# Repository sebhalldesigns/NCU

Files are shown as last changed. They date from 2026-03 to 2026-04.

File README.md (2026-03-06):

# NCU
NCU (Network Control Unit)

## Main Connector Pinout

GND
12V

CAN0_L
CAN0_H
CAN1_L
CAN1_H

ETH_TXP
ETH_TXM
ETH_RXP
ETH_RXM

USB_VBUS
USB_DP
USB_DM
GND

AN_5V
AN_GND
AIN_0
AIN_1
AIN_2
AIN_3
AIN_4
AIN_5
AIN_6
AIN_7

HSD_0
HSD_1
HSD_2
HSD_3

LSD_0
LSD_1
LSD_2
LSD_3

TOTAL:
30

## Sheets

Root/
    CONN_A - OK
    CONN_B - OK
    PWR/ - OK
        PWR_LV_5V - OK
        PWR_3V3 - OK
        PWR_A5V - OK
        PWR_MUX - OK
    PHY_CAN/ - OK
        CAN_BUS (x2) - OK
    PHY_ETH - OK
    DRIVES/ - OK
        LSD (x2) - OK
        HSD (x2) - OK
    INPUTS/ - OK
        INPUT_5V (x4) - OK
        INPUT_20V (x5) - OK
    GPIO/ - OK
        INPUT_3V3 (x4) - OK
    CARD_SD - OK
    CARD_SIM - OK
    MOD_WLAN - BAD
    MOD_PCIE - BAD
    MCU - BAD

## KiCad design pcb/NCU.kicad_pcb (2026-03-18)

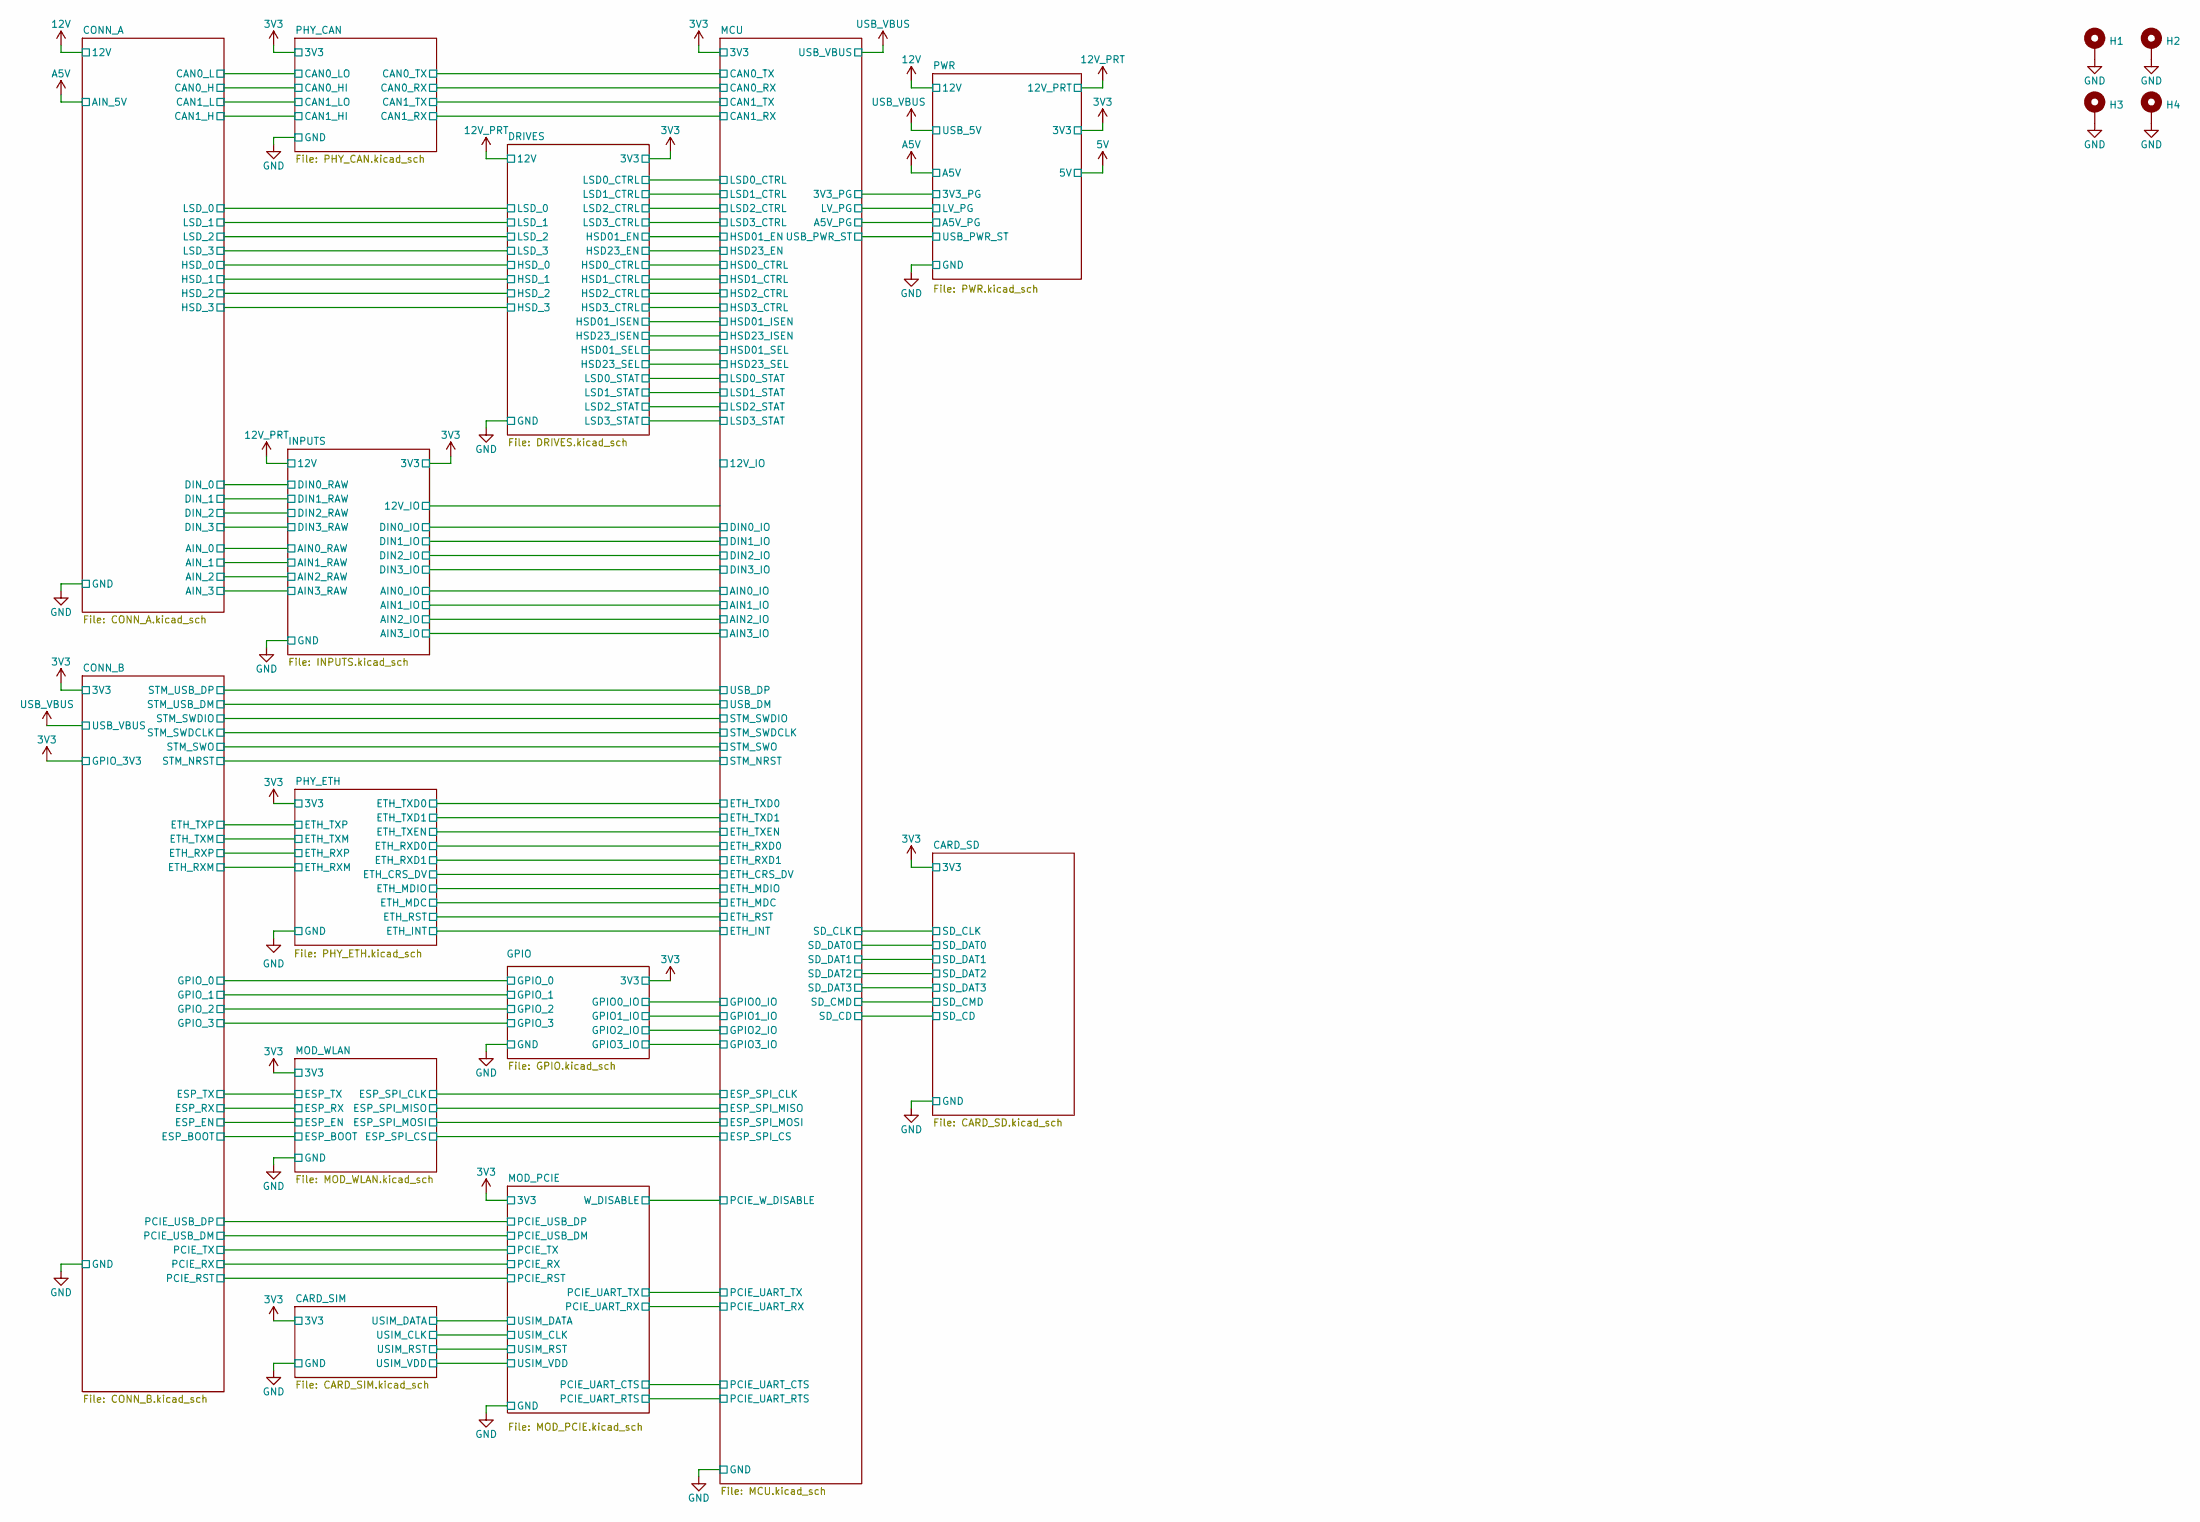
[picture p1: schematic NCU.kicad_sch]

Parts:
H1, H2, H3, H4: MountingHole; MountingHole_3.2mm_M3_Pad

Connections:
GND: H1.1, H2.1, H3.1, H4.1; also elsewhere on the board

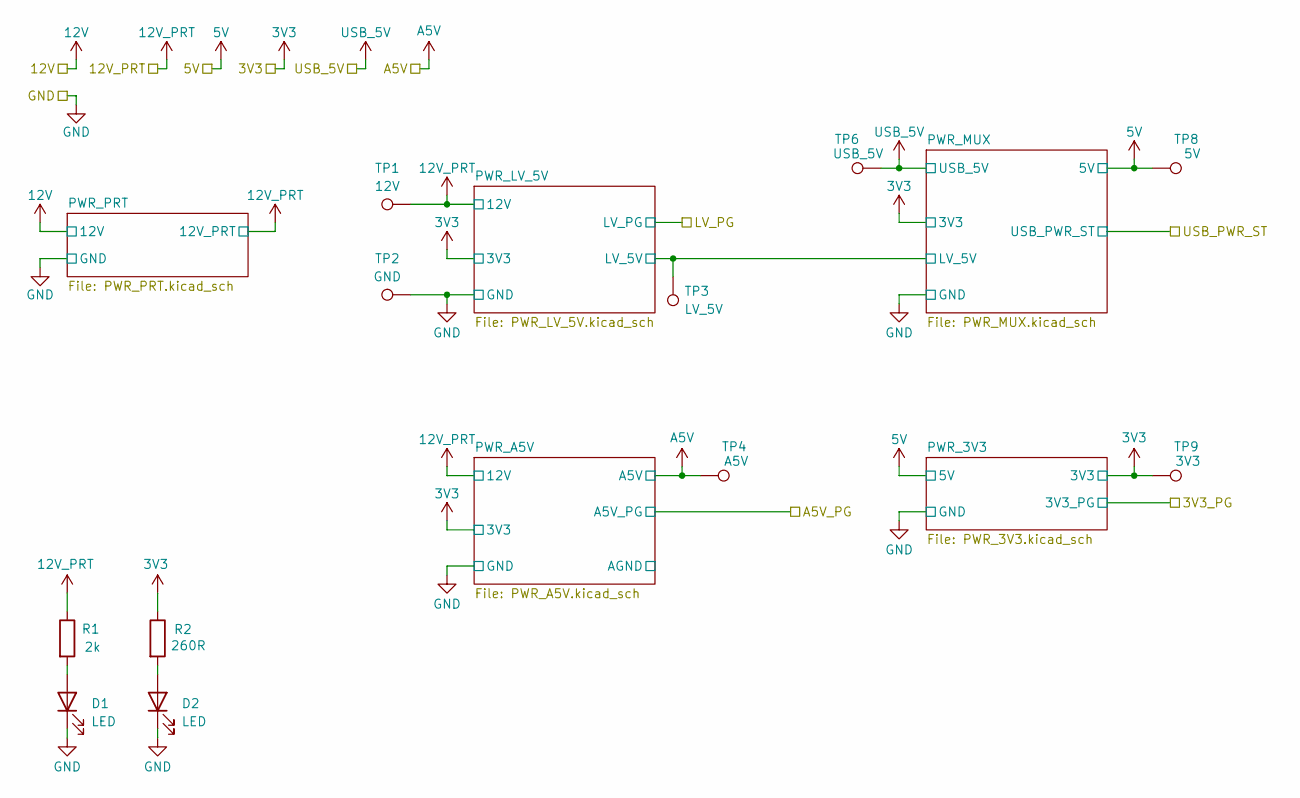
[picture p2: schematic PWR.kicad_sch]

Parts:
D1, D2: LED; LED_0603_1608Metric_Pad1.05x0.95mm_HandSolder
R1: 2k; R_0603_1608Metric_Pad0.98x0.95mm_HandSolder
R2: 260R; R_0603_1608Metric_Pad0.98x0.95mm_HandSolder
TP1: 12V; TestPoint_THTPad_D2.0mm_Drill1.0mm
TP2: GND; TestPoint_THTPad_D2.0mm_Drill1.0mm
TP3: LV_5V; TestPoint_THTPad_D2.0mm_Drill1.0mm
TP4: A5V; TestPoint_THTPad_D2.0mm_Drill1.0mm
TP6: USB_5V; TestPoint_THTPad_D2.0mm_Drill1.0mm
TP8: 5V; TestPoint_THTPad_D2.0mm_Drill1.0mm
TP9: 3V3; TestPoint_THTPad_D2.0mm_Drill1.0mm

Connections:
3V3: R2.1, TP9.1; also elsewhere on the board
5V: TP8.1; also elsewhere on the board
12V_PRT: R1.1, TP1.1; also elsewhere on the board
A5V: TP4.1; also elsewhere on the board
GND: D1.1 (K), D2.1 (K), TP2.1; also elsewhere on the board
LV_5V: TP3.1; also elsewhere on the board
unnamed: D1.2 (A), R1.2
unnamed: D2.2 (A), R2.2
USB_VBUS: TP6.1; also elsewhere on the board

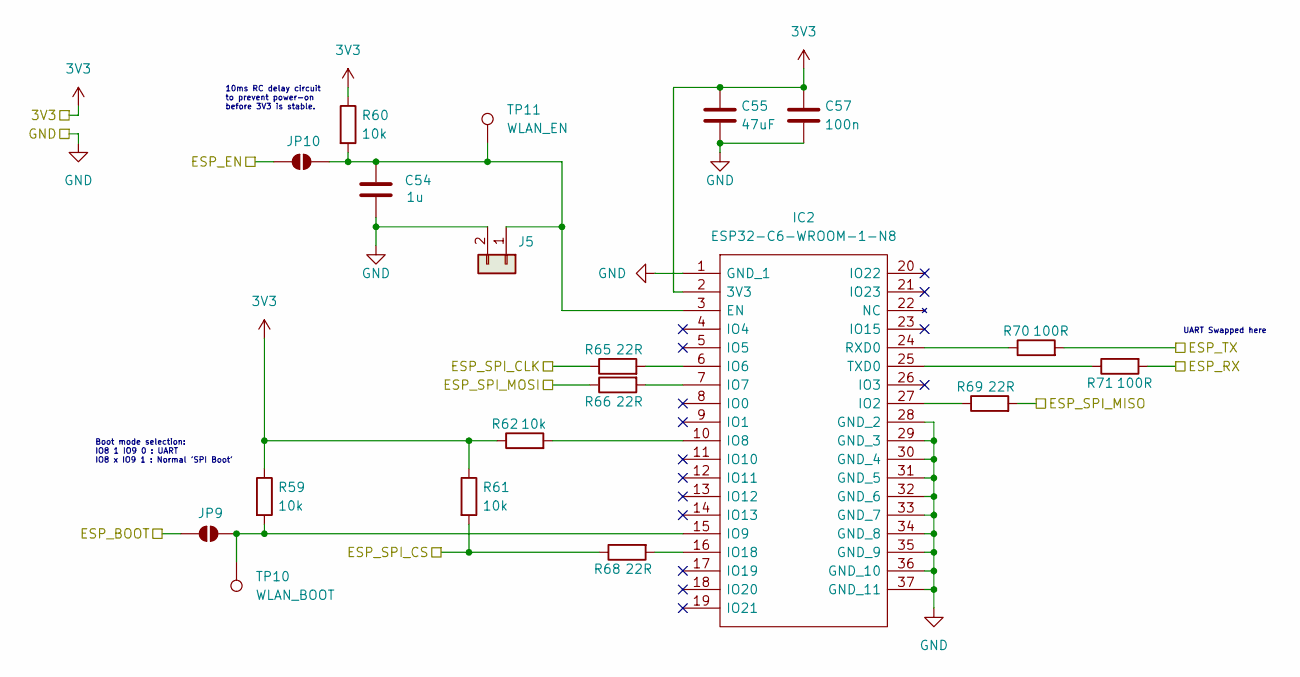
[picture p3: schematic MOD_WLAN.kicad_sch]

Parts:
C54: 1u; C_0603_1608Metric_Pad1.08x0.95mm_HandSolder
C55: 47uF; C_0603_1608Metric_Pad1.08x0.95mm_HandSolder
C57: 100n; C_0603_1608Metric_Pad1.08x0.95mm_HandSolder
IC2: ESP32-C6-WROOM-1-N8; ESP32C6WROOM1N8; Mouser Part Number 356-ESP32C6WROOM1N8
J5: Conn_01x02; PinHeader_1x02_P2.54mm_Vertical
JP9, JP10: SolderJumper_2_Open; SolderJumper-2_P1.3mm_Open_RoundedPad1.0x1.5mm
R59, R60, R61, R62: 10k; R_0603_1608Metric_Pad0.98x0.95mm_HandSolder
R65, R66, R68, R69: 22R; R_0603_1608Metric_Pad0.98x0.95mm_HandSolder
R70, R71: 100R; R_0603_1608Metric_Pad0.98x0.95mm_HandSolder
TP10: WLAN_BOOT; TestPoint_THTPad_D2.0mm_Drill1.0mm
TP11: WLAN_EN; TestPoint_THTPad_D2.0mm_Drill1.0mm

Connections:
3V3: C55.1, C57.1, IC2.2 (3V3), R59.1, R60.1, R61.1, R62.1; also elsewhere on the board
/CONN_B/ESP_BOOT: JP9.1 (A); also elsewhere on the board
/CONN_B/ESP_EN: JP10.1 (A); also elsewhere on the board
/CONN_B/ESP_RX: R71.2; also elsewhere on the board
/CONN_B/ESP_TX: R70.2; also elsewhere on the board
/MCU/ESP_SPI_CLK: R65.1; also elsewhere on the board
/MCU/ESP_SPI_CS: R61.2, R68.1; also elsewhere on the board
/MCU/ESP_SPI_MISO: R69.2; also elsewhere on the board
/MCU/ESP_SPI_MOSI: R66.1; also elsewhere on the board
GND: C54.2, C55.2, C57.2, IC2.1 (GND_1), IC2.28 (GND_2), IC2.29 (GND_3), IC2.30 (GND_4), IC2.31 (GND_5), IC2.32 (GND_6), IC2.33 (GND_7), IC2.34 (GND_8), IC2.35 (GND_9), IC2.36 (GND_10), IC2.37 (GND_11), J5.2; also elsewhere on the board
unnamed: C54.1, IC2.3 (EN), J5.1, JP10.2 (B), R60.2, TP11.1
unnamed: IC2.27 (IO2), R69.1
unnamed: IC2.6 (IO6), R65.2
unnamed: IC2.7 (IO7), R66.2
unnamed: IC2.10 (IO8), R62.2
unnamed: IC2.15 (IO9), JP9.2 (B), R59.2, TP10.1
unnamed: IC2.16 (IO18), R68.2
unnamed: IC2.24 (RXD0), R70.1
unnamed: IC2.25 (TXD0), R71.1

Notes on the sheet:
Boot mode selection: IO8 1 IO9 0 : UART IO8 x IO9 1 : Normal 'SPI Boot'
10ms RC delay circuit to prevent power-on before 3V3 is stable.
UART Swapped here

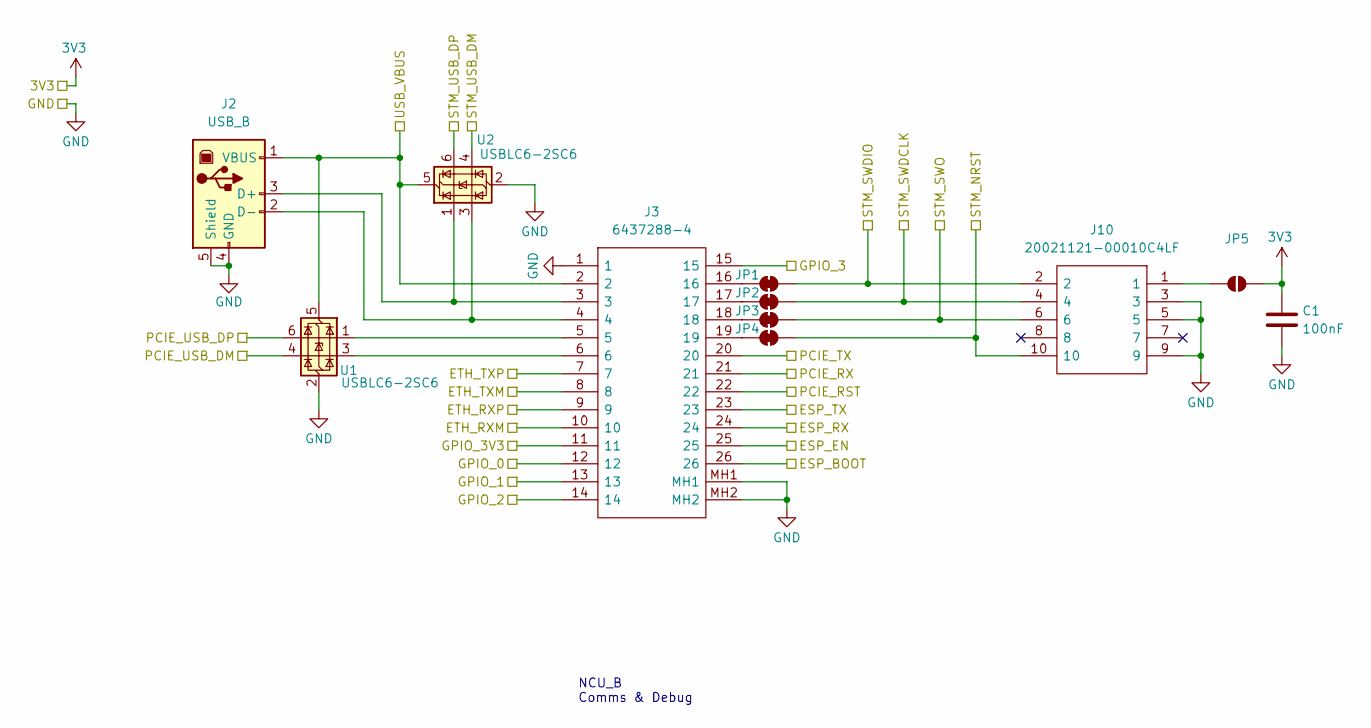
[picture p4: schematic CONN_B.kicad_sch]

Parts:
C1: 100nF; C_0603_1608Metric_Pad1.08x0.95mm_HandSolder
J2: USB_B; USB_B_OST_USB-B1HSxx_Horizontal
J3: 6437288-4; 64372884; Mouser Part Number 571-6437288-4
J10: 20021121-00010C4LF; 2002112100010C4LF; Mouser Part Number 649-202112100010C4LF
JP1, JP2, JP3, JP4: SolderJumper_2_Bridged; SolderJumper-2_P1.3mm_Bridged_RoundedPad1.0x1.5mm
JP5: SolderJumper_2_Open; SolderJumper-2_P1.3mm_Open_RoundedPad1.0x1.5mm
U1, U2: USBLC6-2SC6; SOT-23-6

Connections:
3V3: C1.1, J3.11, JP5.2 (B); also elsewhere on the board
/CONN_B/ESP_BOOT: J3.26; also elsewhere on the board
/CONN_B/ESP_EN: J3.25; also elsewhere on the board
/CONN_B/ESP_RX: J3.24; also elsewhere on the board
/CONN_B/ESP_TX: J3.23; also elsewhere on the board
/CONN_B/ETH_RXM: J3.10; also elsewhere on the board
/CONN_B/ETH_RXP: J3.9; also elsewhere on the board
/CONN_B/ETH_TXM: J3.8; also elsewhere on the board
/CONN_B/ETH_TXP: J3.7; also elsewhere on the board
/CONN_B/GPIO_0: J3.12; also elsewhere on the board
/CONN_B/GPIO_1: J3.13; also elsewhere on the board
/CONN_B/GPIO_2: J3.14; also elsewhere on the board
/CONN_B/GPIO_3: J3.15; also elsewhere on the board
/CONN_B/PCIE_RST: J3.22; also elsewhere on the board
/CONN_B/PCIE_RX: J3.21; also elsewhere on the board
/CONN_B/PCIE_TX: J3.20; also elsewhere on the board
/CONN_B/PCIE_USB_DM: U1.4 (I/O2); also elsewhere on the board
/CONN_B/PCIE_USB_DP: U1.6 (I/O1); also elsewhere on the board
/CONN_B/STM_SWDCLK: J10.4, JP2.2 (B); also elsewhere on the board
/CONN_B/STM_SWDIO: J10.2, JP1.2 (B); also elsewhere on the board
/CONN_B/STM_SWO: J10.6, JP3.2 (B); also elsewhere on the board
/CONN_B/STM_USB_DM: U2.4 (I/O2); also elsewhere on the board
/CONN_B/STM_USB_DP: U2.6 (I/O1); also elsewhere on the board
/MCU/STM_NRST: J10.10, JP4.2 (B); also elsewhere on the board
GND: C1.2, J2.4 (GND), J2.5 (Shield), J3.1, J3.MH1, J3.MH2, J10.3, J10.5, J10.9, U1.2 (GND), U2.2 (GND); also elsewhere on the board
unnamed: J2.3 (D+), J3.3, U2.1 (I/O1)
unnamed: J2.2 (D-), J3.4, U2.3 (I/O2)
unnamed: J3.5, U1.1 (I/O1)
unnamed: J3.6, U1.3 (I/O2)
unnamed: J3.16, JP1.1 (A)
unnamed: J3.17, JP2.1 (A)
unnamed: J3.18, JP3.1 (A)
unnamed: J3.19, JP4.1 (A)
unnamed: J10.1, JP5.1 (A)
USB_VBUS: J2.1 (VBUS), J3.2, U1.5 (VBUS), U2.5 (VBUS); also elsewhere on the board

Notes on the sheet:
NCU_B Comms & Debug

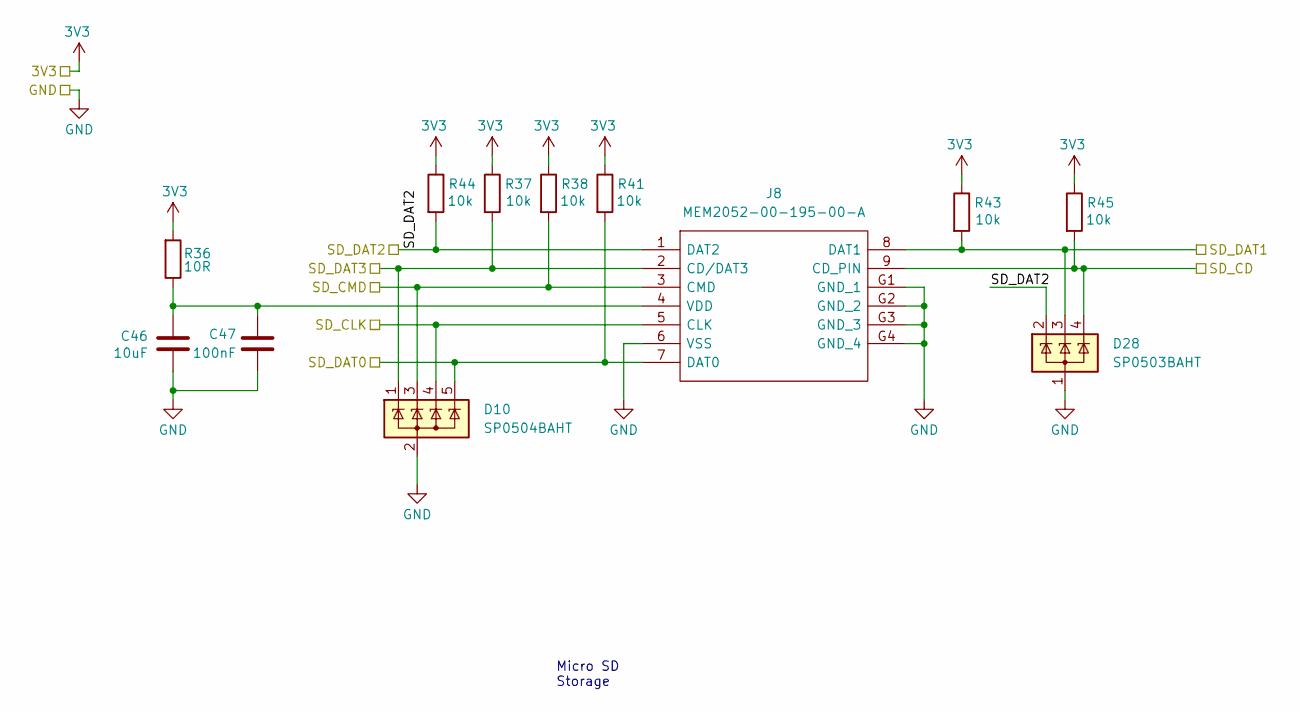
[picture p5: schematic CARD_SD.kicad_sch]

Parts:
C46: 10uF; C_0603_1608Metric_Pad1.08x0.95mm_HandSolder
C47: 100nF; C_0603_1608Metric_Pad1.08x0.95mm_HandSolder
D10: SP0504BAHT; SOT-23-5
D28: SP0503BAHT; SOT-143
J8: MEM2052-00-195-00-A; MEM20520019500A; Mouser Part Number 640-MEM20520019500A
R36: 10R; R_0603_1608Metric_Pad0.98x0.95mm_HandSolder
R37, R38, R41, R43, R44, R45: 10k; R_0603_1608Metric_Pad0.98x0.95mm_HandSolder

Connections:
3V3: R36.2, R37.1, R38.1, R41.1, R43.1, R44.1, R45.1; also elsewhere on the board
/CARD_SD/SD_CD: D28.4 (K), J8.9 (CD_PIN), R45.2; also elsewhere on the board
/CARD_SD/SD_CLK: D10.4 (K), J8.5 (CLK); also elsewhere on the board
/CARD_SD/SD_CMD: D10.3 (K), J8.3 (CMD), R38.2; also elsewhere on the board
/CARD_SD/SD_DAT0: D10.5 (K), J8.7 (DAT0), R41.2; also elsewhere on the board
/CARD_SD/SD_DAT1: D28.3 (K), J8.8 (DAT1), R43.2; also elsewhere on the board
/CARD_SD/SD_DAT2: D28.2 (K), J8.1 (DAT2), R44.2; also elsewhere on the board
/CARD_SD/SD_DAT3: D10.1 (K), J8.2 (CD/DAT3), R37.2; also elsewhere on the board
GND: C46.2, C47.2, D10.2 (A), D28.1 (A), J8.6 (VSS), J8.G1 (GND_1), J8.G2 (GND_2), J8.G3 (GND_3), J8.G4 (GND_4); also elsewhere on the board
unnamed: C46.1, C47.1, J8.4 (VDD), R36.1

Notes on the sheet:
Micro SD Storage

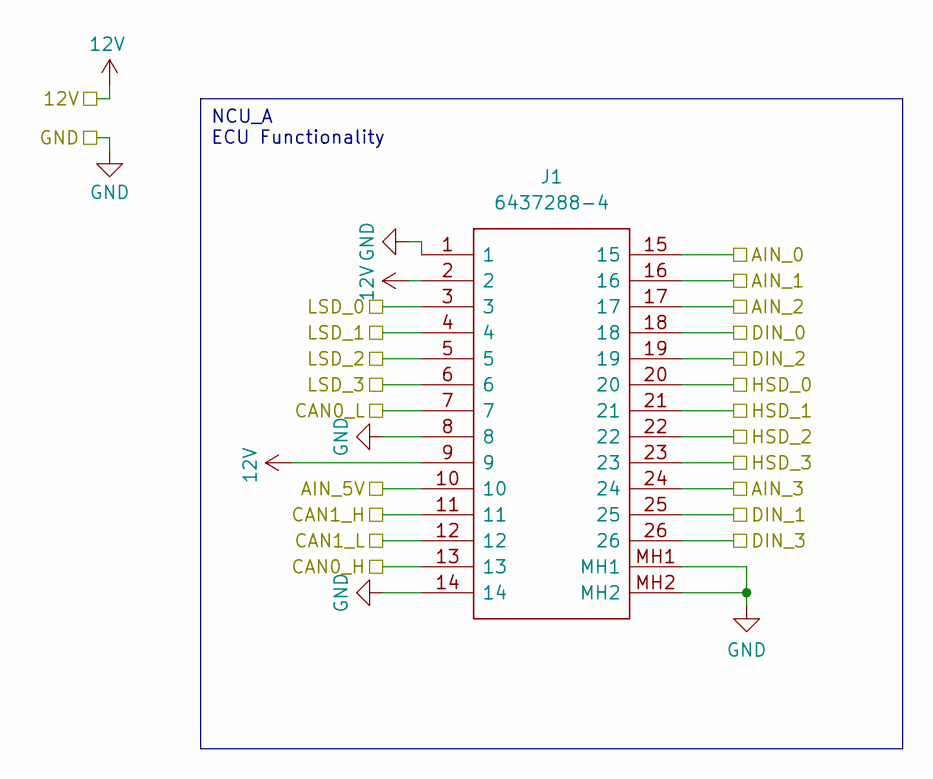
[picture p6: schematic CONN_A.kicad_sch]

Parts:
J1: 6437288-4; 64372884; Mouser Part Number 571-6437288-4

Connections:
12V: J1.2, J1.9; also elsewhere on the board
/CONN_A/AIN_0: J1.15; also elsewhere on the board
/CONN_A/AIN_1: J1.16; also elsewhere on the board
/CONN_A/AIN_2: J1.17; also elsewhere on the board
/CONN_A/AIN_3: J1.24; also elsewhere on the board
/CONN_A/CAN0_H: J1.13; also elsewhere on the board
/CONN_A/CAN0_L: J1.7; also elsewhere on the board
/CONN_A/CAN1_H: J1.11; also elsewhere on the board
/CONN_A/CAN1_L: J1.12; also elsewhere on the board
/CONN_A/DIN_0: J1.18; also elsewhere on the board
/CONN_A/DIN_1: J1.25; also elsewhere on the board
/CONN_A/DIN_2: J1.19; also elsewhere on the board
/CONN_A/DIN_3: J1.26; also elsewhere on the board
/CONN_A/HSD_0: J1.20; also elsewhere on the board
/CONN_A/HSD_1: J1.21; also elsewhere on the board
/CONN_A/HSD_2: J1.22; also elsewhere on the board
/CONN_A/HSD_3: J1.23; also elsewhere on the board
/CONN_A/LSD_0: J1.3; also elsewhere on the board
/CONN_A/LSD_1: J1.4; also elsewhere on the board
/CONN_A/LSD_2: J1.5; also elsewhere on the board
/CONN_A/LSD_3: J1.6; also elsewhere on the board
A5V: J1.10; also elsewhere on the board
GND: J1.1, J1.8, J1.14, J1.MH1, J1.MH2; also elsewhere on the board

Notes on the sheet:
NCU_A ECU Functionality

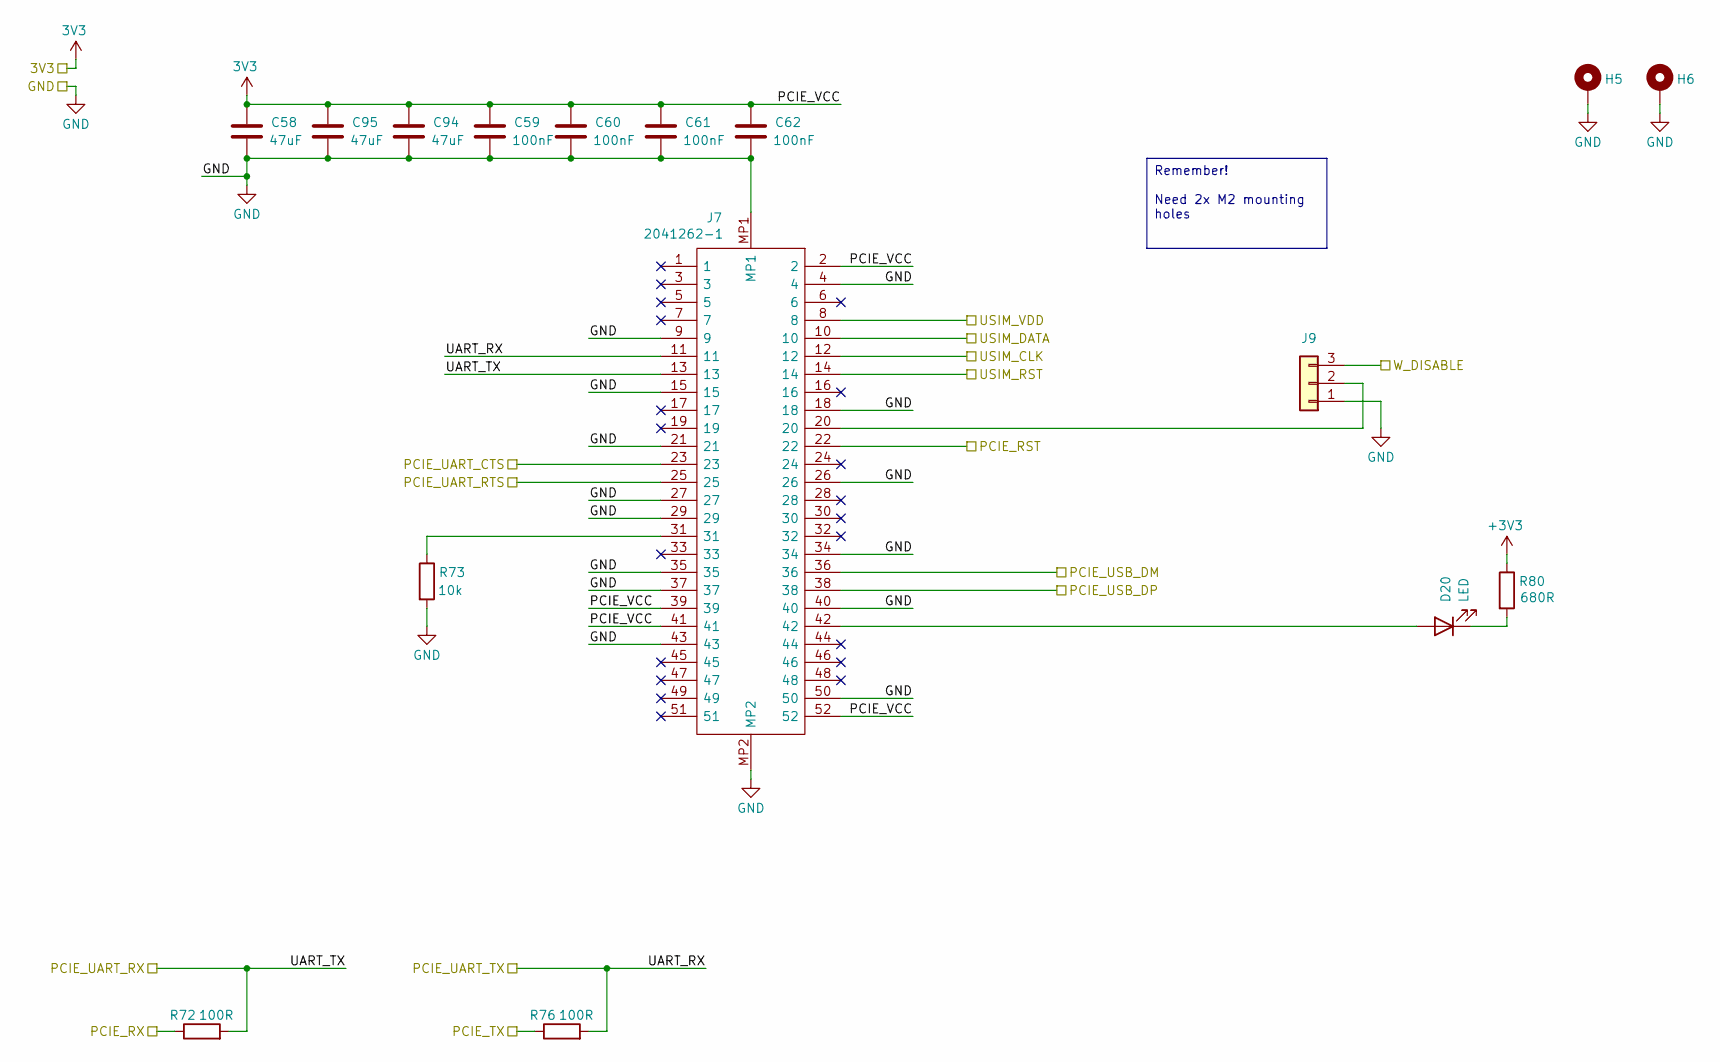
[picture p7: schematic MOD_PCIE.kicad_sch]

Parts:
C58, C94, C95: 47uF; C_0603_1608Metric_Pad1.08x0.95mm_HandSolder
C59, C60, C61, C62: 100nF; C_0603_1608Metric_Pad1.08x0.95mm_HandSolder
D20: LED; LED_0603_1608Metric_Pad1.05x0.95mm_HandSolder
H5, H6: MountingHole_Pad; MountingHole_2.7mm_M2.5_Pad
J7: 2041262-1; 20412621; Mouser Part Number 571-2041262-1
J9: Conn_01x03; PinHeader_1x03_P2.54mm_Vertical
R72, R76: 100R; R_0603_1608Metric_Pad0.98x0.95mm_HandSolder
R73: 10k; R_0603_1608Metric_Pad0.98x0.95mm_HandSolder
R80: 680R; R_0603_1608Metric_Pad0.98x0.95mm_HandSolder

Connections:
3V3: C58.1, C59.1, C60.1, C61.1, C62.1, C94.1, C95.1, J7.2, J7.39, J7.41, J7.52; also elsewhere on the board
+3V3: R80.1
/CARD_SIM/USIM_CLK: J7.12; also elsewhere on the board
/CARD_SIM/USIM_DATA: J7.10; also elsewhere on the board
/CARD_SIM/USIM_RST: J7.14; also elsewhere on the board
/CARD_SIM/USIM_VDD: J7.8; also elsewhere on the board
/CONN_B/PCIE_RST: J7.22; also elsewhere on the board
/CONN_B/PCIE_RX: R72.1; also elsewhere on the board
/CONN_B/PCIE_TX: R76.1; also elsewhere on the board
/CONN_B/PCIE_USB_DM: J7.36; also elsewhere on the board
/CONN_B/PCIE_USB_DP: J7.38; also elsewhere on the board
/MCU/PCIE_UART_CTS: J7.23; also elsewhere on the board
/MCU/PCIE_UART_RTS: J7.25; also elsewhere on the board
/MCU/PCIE_W_DISABLE: J9.3; also elsewhere on the board
/MOD_PCIE/UART_RX: J7.11, R76.2; also elsewhere on the board
/MOD_PCIE/UART_TX: J7.13, R72.2; also elsewhere on the board
GND: C58.2, C59.2, C60.2, C61.2, C62.2, C94.2, C95.2, H5.1, H6.1, J7.4, J7.9, J7.15, J7.18, J7.21, J7.26, J7.27, J7.29, J7.34, J7.35, J7.37, J7.40, J7.43, J7.50, J7.MP1, J7.MP2, J9.1, R73.2; also elsewhere on the board
unnamed: D20.2 (A), J7.42
unnamed: D20.1 (K), R80.2
unnamed: J7.31, R73.1
unnamed: J7.20, J9.2

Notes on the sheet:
Remember! Need 2x M2 mounting holes

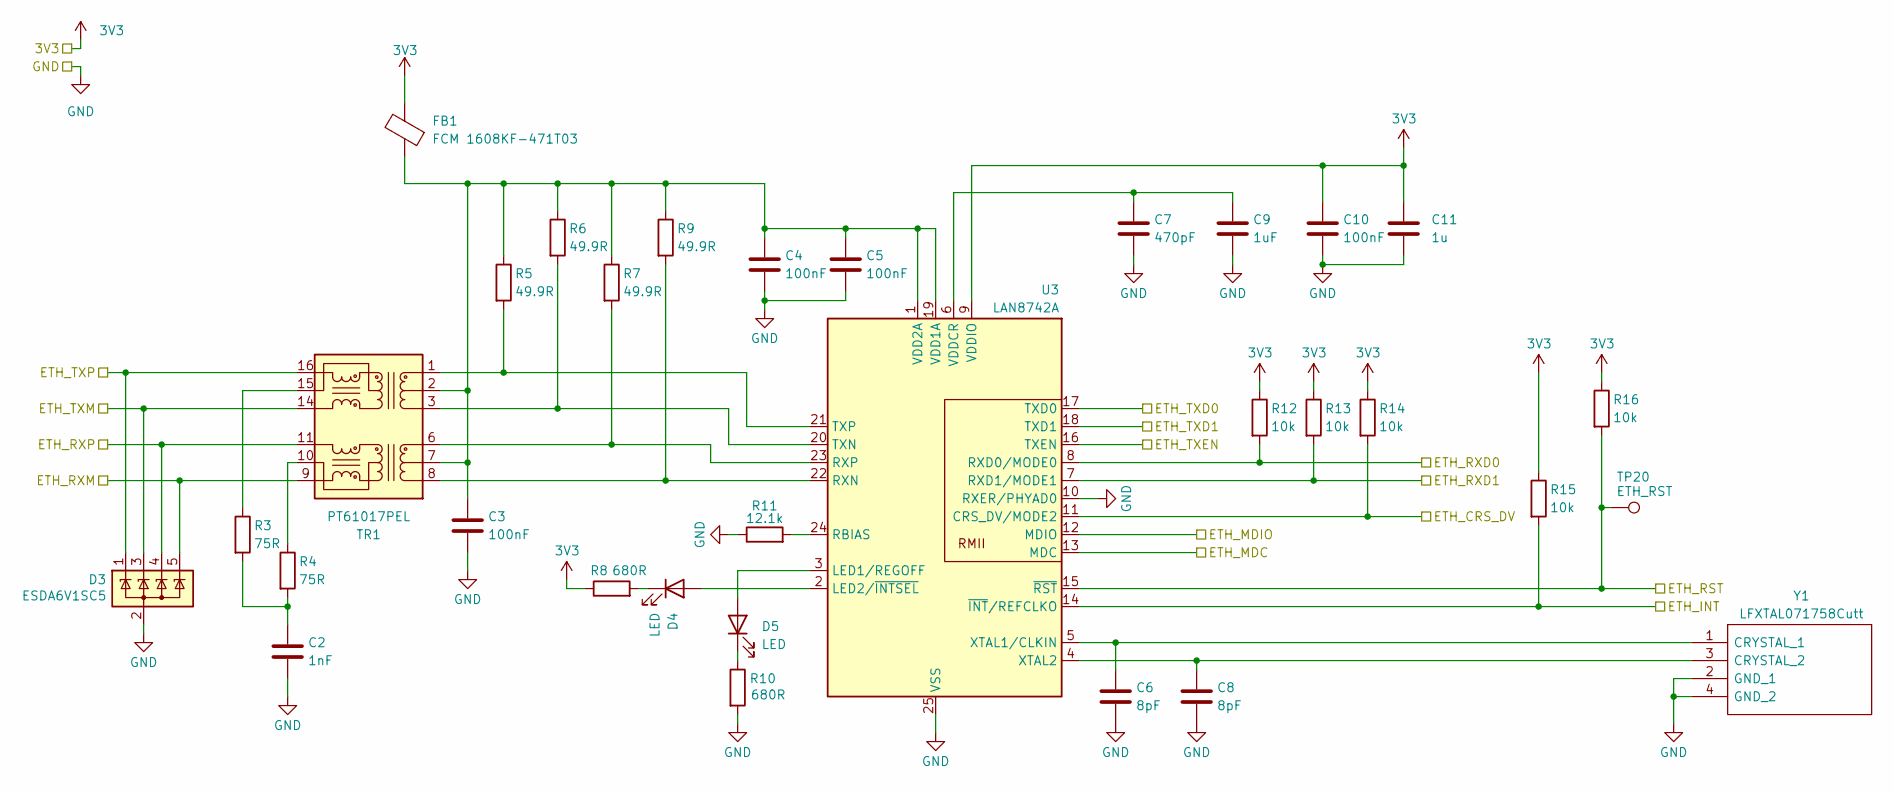
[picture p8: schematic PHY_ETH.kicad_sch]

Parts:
C2: 1nF; C_0603_1608Metric_Pad1.08x0.95mm_HandSolder
C3, C4, C5, C10: 100nF; C_0603_1608Metric_Pad1.08x0.95mm_HandSolder
C6, C8: 8pF; C_0603_1608Metric_Pad1.08x0.95mm_HandSolder
C7: 470pF; C_0603_1608Metric_Pad1.08x0.95mm_HandSolder
C9: 1uF; C_0603_1608Metric_Pad1.08x0.95mm_HandSolder
C11: 1u; C_0603_1608Metric_Pad1.08x0.95mm_HandSolder
D3: ESDA6V1SC5; SOT-23-5
D4, D5: LED; LED_0603_1608Metric_Pad1.05x0.95mm_HandSolder
FB1: FCM 1608KF-471T03; L_0603_1608Metric_Pad1.05x0.95mm_HandSolder
R3, R4: 75R; R_0603_1608Metric_Pad0.98x0.95mm_HandSolder
R5, R6, R7, R9: 49.9R; R_0603_1608Metric_Pad0.98x0.95mm_HandSolder
R8, R10: 680R; R_0603_1608Metric_Pad0.98x0.95mm_HandSolder
R11: 12.1k; R_0603_1608Metric_Pad0.98x0.95mm_HandSolder
R12, R13, R14, R15, R16: 10k; R_0603_1608Metric_Pad0.98x0.95mm_HandSolder
TP20: ETH_RST; TestPoint_THTPad_D2.0mm_Drill1.0mm
TR1: PT61017PEL; Transformer_Ethernet_Bourns_PT61017PEL
U3: LAN8742A; VQFN-24-1EP_4x4mm_P0.5mm_EP2.5x2.5mm_ThermalVias
Y1: LFXTAL071758Cutt; Mouser Part Number 449-LFXTAL071758CUTT

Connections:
3V3: C10.1, C11.1, FB1.2, R8.1, R12.1, R13.1, R14.1, R15.1, R16.1, U3.9 (VDDIO); also elsewhere on the board
/CONN_B/ETH_RXM: D3.5 (K), TR1.9 (RX-); also elsewhere on the board
/CONN_B/ETH_RXP: D3.4 (K), TR1.11 (RX+); also elsewhere on the board
/CONN_B/ETH_TXM: D3.3 (K), TR1.14 (TX-); also elsewhere on the board
/CONN_B/ETH_TXP: D3.1 (K), TR1.16 (TX+); also elsewhere on the board
/MCU/ETH_CRS_DV: R14.2, U3.11 (CRS_DV/MODE2); also elsewhere on the board
/MCU/ETH_INT: R15.2, U3.14 (~INT/REFCLKO); also elsewhere on the board
/MCU/ETH_MDC: U3.13 (MDC); also elsewhere on the board
/MCU/ETH_MDIO: U3.12 (MDIO); also elsewhere on the board
/MCU/ETH_RST: R16.2, TP20.1, U3.15 (~RST); also elsewhere on the board
/MCU/ETH_RXD0: R12.2, U3.8 (RXD0/MODE0); also elsewhere on the board
/MCU/ETH_RXD1: R13.2, U3.7 (RXD1/MODE1); also elsewhere on the board
/MCU/ETH_TXD0: U3.17 (TXD0); also elsewhere on the board
/MCU/ETH_TXD1: U3.18 (TXD1); also elsewhere on the board
/MCU/ETH_TXEN: U3.16 (TXEN); also elsewhere on the board
GND: C2.2, C3.2, C4.2, C5.2, C6.2, C7.2, C8.2, C9.2, C10.2, C11.2, D3.2 (A), R10.2, R11.1, U3.10 (RXER/PHYAD0), U3.25 (VSS), Y1.2 (GND_1), Y1.4 (GND_2); also elsewhere on the board
unnamed: C2.1, R3.2, R4.2
unnamed: D4.2 (A), U3.2 (LED2/~INTSEL)
unnamed: D4.1 (K), R8.2
unnamed: D5.2 (A), U3.3 (LED1/REGOFF)
unnamed: D5.1 (K), R10.1
unnamed: C3.1, C4.1, C5.1, FB1.1, R5.1, R6.1, R7.1, R9.1, TR1.2 (C_TD), TR1.7 (C_RD), U3.1 (VDD2A), U3.19 (VDD1A)
unnamed: R4.1, TR1.10 (C_RX)
unnamed: R3.1, TR1.15 (C_TX)
unnamed: R7.2, TR1.6 (RD+), U3.23 (RXP)
unnamed: R9.2, TR1.8 (RD-), U3.22 (RXN)
unnamed: R5.2, TR1.1 (TD+), U3.21 (TXP)
unnamed: R6.2, TR1.3 (TD-), U3.20 (TXN)
unnamed: R11.2, U3.24 (RBIAS)
unnamed: C7.1, C9.1, U3.6 (VDDCR)
unnamed: C6.1, U3.5 (XTAL1/CLKIN), Y1.1 (CRYSTAL_1)
unnamed: C8.1, U3.4 (XTAL2), Y1.3 (CRYSTAL_2)

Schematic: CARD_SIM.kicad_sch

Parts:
C49: 100n; C_0603_1608Metric_Pad1.08x0.95mm_HandSolder
D13: SP0503BAHT; SOT-143
J6: SF56K006VBAR2000; Mouser Part Number 656-SF56K006VBAR2000

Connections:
/CARD_SIM/USIM_CLK: D13.3 (K), J6.C3 (CLK); also elsewhere on the board
/CARD_SIM/USIM_DATA: D13.4 (K), J6.C7 (I/O); also elsewhere on the board
/CARD_SIM/USIM_RST: D13.2 (K), J6.C2 (RST); also elsewhere on the board
/CARD_SIM/USIM_VDD: C49.1, J6.C1 (VCC); also elsewhere on the board
GND: C49.2, D13.1 (A), J6.C5 (GND_1), J6.D1 (DUMMY_1), J6.D2 (DUMMY_2), J6.D3 (DUMMY_3), J6.D4 (DUMMY_4), J6.D5 (DUMMY_5), J6.D6 (DUMMY_6), J6.DSW1 (GND_2), J6.DSW2, J6.G1 (GND1), J6.G2 (GND2), J6.G3 (GND3), J6.G4 (GND4), J6.G5 (GND5), J6.G6 (GND6); also elsewhere on the board

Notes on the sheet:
Mini SIM Cellular

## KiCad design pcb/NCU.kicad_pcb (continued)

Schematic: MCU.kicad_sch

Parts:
C89: 100nF; C_0603_1608Metric_Pad1.08x0.95mm_HandSolder
C90, C92: 8.2pF; C_0603_1608Metric_Pad1.08x0.95mm_HandSolder
C91, C93: 5.1pF; C_0603_1608Metric_Pad1.08x0.95mm_HandSolder
D26: LED; LED_0603_1608Metric_Pad1.05x0.95mm_HandSolder
D27: SP0504BAHT; SOT-23-5
JP12: SolderJumper_2_Open; SolderJumper-2_P1.3mm_Open_RoundedPad1.0x1.5mm
R123, R125, R126: 10k; R_0603_1608Metric_Pad0.98x0.95mm_HandSolder
R124: 260R; R_0603_1608Metric_Pad0.98x0.95mm_HandSolder
TP18: BOOT; TestPoint_THTPad_D2.0mm_Drill1.0mm
U7: STM32H745ZITx; LQFP-144_20x20mm_P0.5mm
Y2: NX3215SA-32.768K-STD-MUS-2; NX3215SA32768KSTDMUS2; Mouser Part Number 344-NX3215SA32768K2
Y3: Crystal_GND24; NX2016SA32MEXS00ACS06465

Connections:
3V3: JP12.2 (B), R123.1, R126.1, U7.7 (VDD), U7.8 (VBAT), U7.13 (VDD), U7.16 (VDDSMPS), U7.19 (VDD), U7.32 (VDD), U7.42 (VDD), U7.56 (VDD), U7.71 (VDD), U7.79 (VDD), U7.90 (VDD50_USB), U7.91 (VDD33_USB), U7.92 (VDD), U7.106 (VDD), U7.119 (VDD), U7.129 (VDD), U7.144 (VDD); also elsewhere on the board
/CARD_SD/SD_CD: U7.99 (PA10); also elsewhere on the board
/CARD_SD/SD_CLK: U7.111 (SDMMC1_CK); also elsewhere on the board
/CARD_SD/SD_CMD: U7.114 (SDMMC1_CMD); also elsewhere on the board
/CARD_SD/SD_DAT0: U7.95 (SDMMC1_D0); also elsewhere on the board
/CARD_SD/SD_DAT1: U7.96 (SDMMC1_D1); also elsewhere on the board
/CARD_SD/SD_DAT2: U7.109 (SDMMC1_D2); also elsewhere on the board
/CARD_SD/SD_DAT3: U7.110 (SDMMC1_D3); also elsewhere on the board
/CONN_B/STM_SWDCLK: D27.3 (K), U7.107 (DEBUG_JTCK-SWCLK); also elsewhere on the board
/CONN_B/STM_SWDIO: D27.1 (K), U7.102 (DEBUG_JTMS-SWDIO); also elsewhere on the board
/CONN_B/STM_SWO: D27.5 (K), U7.130 (DEBUG_JTDO-SWO); also elsewhere on the board
/CONN_B/STM_USB_DM: U7.100 (USB_OTG_FS_DM); also elsewhere on the board
/CONN_B/STM_USB_DP: U7.101 (USB_OTG_FS_DP); also elsewhere on the board
/DRIVES/HSD0_CTRL: U7.82 (TIM4_CH1); also elsewhere on the board
/DRIVES/HSD1_CTRL: U7.83 (TIM4_CH2); also elsewhere on the board
/DRIVES/HSD01_EN: U7.81 (PD11); also elsewhere on the board
/DRIVES/HSD01_ISEN: U7.20 (ADC3_INP8); also elsewhere on the board
/DRIVES/HSD01_SEL: U7.21 (PF7); also elsewhere on the board
/DRIVES/HSD2_CTRL: U7.136 (TIM4_CH3); also elsewhere on the board
/DRIVES/HSD3_CTRL: U7.137 (TIM4_CH4); also elsewhere on the board
/DRIVES/HSD23_EN: U7.134 (PB7); also elsewhere on the board
/DRIVES/HSD23_ISEN: U7.22 (ADC3_INP7); also elsewhere on the board
/DRIVES/HSD23_SEL: U7.23 (PF9); also elsewhere on the board
/DRIVES/LSD0_CTRL: U7.59 (TIM1_CH1); also elsewhere on the board
/DRIVES/LSD0_STAT: U7.60 (PE10); also elsewhere on the board
/DRIVES/LSD1_CTRL: U7.61 (TIM1_CH2); also elsewhere on the board
/DRIVES/LSD1_STAT: U7.62 (PE12); also elsewhere on the board
/DRIVES/LSD2_CTRL: U7.63 (TIM1_CH3); also elsewhere on the board
/DRIVES/LSD2_STAT: U7.57 (PE7); also elsewhere on the board
/DRIVES/LSD3_CTRL: U7.64 (TIM1_CH4); also elsewhere on the board
/DRIVES/LSD3_STAT: U7.58 (PE8); also elsewhere on the board
/GPIO/GPIO0_IO: U7.43 (DAC1_OUT1); also elsewhere on the board
/GPIO/GPIO1_IO: U7.44 (DAC1_OUT2); also elsewhere on the board
/GPIO/GPIO2_IO: U7.37 (ADC1_INP16); also elsewhere on the board
/GPIO/GPIO3_IO: U7.38 (ADC1_INP17); also elsewhere on the board
/INPUTS/AIN0_IO: U7.40 (ADC1_INP15); also elsewhere on the board
/INPUTS/AIN1_IO: U7.45 (ADC1_INP3); also elsewhere on the board
/INPUTS/AIN2_IO: U7.50 (ADC1_INP5); also elsewhere on the board
/INPUTS/AIN3_IO: U7.28 (ADC1_INP10); also elsewhere on the board
/INPUTS/DIN0_IO: U7.30 (ADC3_INP0); also elsewhere on the board
/INPUTS/DIN1_IO: U7.31 (ADC3_INP1); also elsewhere on the board
/INPUTS/DIN2_IO: U7.24 (ADC3_INN2); also elsewhere on the board
/INPUTS/DIN3_IO: U7.52 (ADC1_INP2); also elsewhere on the board
/MCU/3V3_PG: U7.116 (PD4); also elsewhere on the board
/MCU/12V_IO: U7.53 (ADC2_INP6)
/MCU/A5V_PG: U7.117 (PD5); also elsewhere on the board
/MCU/CAN0_RX: U7.112 (FDCAN1_RX); also elsewhere on the board
/MCU/CAN0_TX: U7.113 (FDCAN1_TX); also elsewhere on the board
/MCU/CAN1_RX: U7.132 (FDCAN2_RX); also elsewhere on the board
/MCU/CAN1_TX: U7.133 (FDCAN2_TX); also elsewhere on the board
/MCU/ESP_SPI_CLK: U7.1 (SPI4_SCK); also elsewhere on the board
/MCU/ESP_SPI_CS: U7.3 (SPI4_NSS); also elsewhere on the board
/MCU/ESP_SPI_MISO: U7.4 (SPI4_MISO); also elsewhere on the board
/MCU/ESP_SPI_MOSI: U7.5 (SPI4_MOSI); also elsewhere on the board
/MCU/ETH_CRS_DV: U7.46 (ETH_CRS_DV); also elsewhere on the board
/MCU/ETH_INT: U7.49 (PB0); also elsewhere on the board
/MCU/ETH_MDC: U7.29 (ETH_MDC); also elsewhere on the board
/MCU/ETH_MDIO: U7.39 (ETH_MDIO); also elsewhere on the board
/MCU/ETH_RST: U7.108 (PA15); also elsewhere on the board
/MCU/ETH_RXD0: U7.47 (ETH_RXD0); also elsewhere on the board
/MCU/ETH_RXD1: U7.48 (ETH_RXD1); also elsewhere on the board
/MCU/ETH_TXD0: U7.72 (ETH_TXD0); also elsewhere on the board
/MCU/ETH_TXD1: U7.73 (ETH_TXD1); also elsewhere on the board
/MCU/ETH_TXEN: U7.67 (ETH_TX_EN); also elsewhere on the board
/MCU/LV_PG: U7.115 (PD3); also elsewhere on the board
/MCU/MCU Power/VDDLDO: U7.70 (VDDLDO), U7.105 (VDDLDO), U7.143 (VDDLDO); also elsewhere on the board
/MCU/PCIE_UART_CTS: U7.84 (UART8_CTS); also elsewhere on the board
/MCU/PCIE_UART_RTS: U7.85 (UART8_RTS); also elsewhere on the board
/MCU/PCIE_W_DISABLE: U7.120 (PD6); also elsewhere on the board
/MCU/RCC_OSC32_IN: C93.1, U7.10 (RCC_OSC32_IN), Y2.2
/MCU/RCC_OSC32_OUT: C91.1, U7.11 (RCC_OSC32_OUT), Y2.1
/MCU/RCC_OSC_IN: C92.1, U7.25 (RCC_OSC_IN), Y3.1
/MCU/RCC_OSC_OUT: C90.1, U7.26 (RCC_OSC_OUT), Y3.3
/MCU/STM_NRST: C89.1, D27.4 (K), R123.2, U7.27 (NRST); also elsewhere on the board
/MCU/VCAP: U7.68 (VCAP), U7.103 (VCAP), U7.140 (VCAP); also elsewhere on the board
/MCU/VFBSMPS: U7.17 (VFBSMPS); also elsewhere on the board
/MCU/VLXSMPS: U7.15 (VLXSMPS); also elsewhere on the board
/MCU/VREF+: U7.35 (VREF+), U7.36 (VDDA); also elsewhere on the board
/MOD_PCIE/UART_RX: U7.139 (UART8_TX); also elsewhere on the board
/MOD_PCIE/UART_TX: U7.138 (UART8_RX); also elsewhere on the board
GND: C89.2, C90.2, C91.2, C92.2, C93.2, D26.1 (K), D27.2 (A), R125.2, U7.6 (VSS), U7.12 (VSS), U7.14 (VSSSMPS), U7.18 (VSS), U7.33 (VSS), U7.34 (VSSA), U7.41 (VSS), U7.55 (VSS), U7.69 (VSS), U7.80 (VSS), U7.89 (VSS), U7.104 (VSS), U7.118 (VSS), U7.128 (VSS), U7.141 (VSS), Y3.2, Y3.4; also elsewhere on the board
unnamed: D26.2 (A), R124.2
unnamed: JP12.1 (A), R125.1, TP18.1, U7.135 (BOOT0)
unnamed: R126.2, U7.142 (PDR_ON)
unnamed: R124.1, U7.65 (PE15)
USB_VBUS: U7.98 (USB_OTG_FS_VBUS); also elsewhere on the board

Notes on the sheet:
Solder jumper for boot recovery - bridge to enter system bootloader mode

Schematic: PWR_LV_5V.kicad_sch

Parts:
C73, C74: 4.7uF; C_1210_3225Metric_Pad1.33x2.70mm_HandSolder
C75, C76: 0.1uF; C_0603_1608Metric_Pad1.08x0.95mm_HandSolder
C77: 33pF; C_0603_1608Metric_Pad1.08x0.95mm_HandSolder
C78, C79: 47uF; C_1210_3225Metric_Pad1.33x2.70mm_HandSolder
IC6: LMR51460SQDRRRQ1; SON50P300X300X80-13N-D; Manufacturer_Part_Number LMR51460SQDRRRQ1
L2: 4.7uH; L_Coilcraft_XAL7030-472
NT2: NetTie_2; NetTie-2_SMD_Pad0.5mm
R110: 19.1k; R_0603_1608Metric_Pad0.98x0.95mm_HandSolder
R111, R112: 100k; R_0603_1608Metric_Pad0.98x0.95mm_HandSolder
R113: 1k; R_0603_1608Metric_Pad0.98x0.95mm_HandSolder

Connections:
3V3: R111.2; also elsewhere on the board
12V_PRT: C73.1, C74.1, C75.1, IC6.9 (EN), IC6.10 (VIN_1), IC6.11 (VIN_2), IC6.12 (VIN_3); also elsewhere on the board
/MCU/LV_PG: IC6.5 (PG), R111.1; also elsewhere on the board
/PWR/PWR_LV_5V/LMR_FB: C77.2, IC6.7 (FB), R110.1, R112.2
/PWR/PWR_LV_5V/LMR_SW: C76.1, IC6.1 (SW_1), IC6.2 (SW_2), IC6.3 (SW_3), L2.1
GND: C73.2, C74.2, C75.2, C78.2, C79.2, IC6.13 (PGND/DAP), NT2.1; also elsewhere on the board
LV_5V: C78.1, C79.1, L2.2, R112.1, R113.1; also elsewhere on the board
unnamed: C77.1, R113.2
unnamed: IC6.8 (AGND), NT2.2, R110.2
unnamed: C76.2, IC6.4 (BOOT)

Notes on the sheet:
12V-5V Supply Place near to 12V input

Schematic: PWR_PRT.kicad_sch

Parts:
D25: SBR2065D1-13; SBR2065D113; Mouser Part Number 621-SBR2065D1-13
U6: TA6F27CA; D_SOD-128

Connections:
12V: D25.1 (A_1), D25.3 (A_2); also elsewhere on the board
12V_PRT: D25.2 (COM_K), U6.2; also elsewhere on the board
GND: U6.1; also elsewhere on the board

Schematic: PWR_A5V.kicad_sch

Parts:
C86, C87: 1uF; C_0603_1608Metric_Pad1.08x0.95mm_HandSolder
IC8: LP2951-50DRG4; SOIC127P600X175-8N; Mouser Part Number 595-LP2951-50DRG4
R118: 100k; R_0603_1608Metric_Pad0.98x0.95mm_HandSolder

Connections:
3V3: R118.2; also elsewhere on the board
12V_PRT: C86.1, IC8.8 (INPUT); also elsewhere on the board
/MCU/A5V_PG: IC8.5 (~ERROR), R118.1; also elsewhere on the board
A5V: C87.1, IC8.1 (OUTPUT), IC8.2 (SENSE); also elsewhere on the board
GND: C86.2, C87.2, IC8.3 (SHUTDOWN), IC8.4 (GND); also elsewhere on the board
unnamed: IC8.6 (VTAP), IC8.7 (FEEDBACK)

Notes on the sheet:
A5V Analog power supply

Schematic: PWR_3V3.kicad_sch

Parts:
C80: 4.7nF; C_0603_1608Metric_Pad1.08x0.95mm_HandSolder
C81: 22uF; C_0603_1608Metric_Pad1.08x0.95mm_HandSolder
C82: 10pF; C_0603_1608Metric_Pad1.08x0.95mm_HandSolder
C83, C84: 22uF; L_1206_3216Metric_Pad1.22x1.90mm_HandSolder
C85: 10uF; C_0603_1608Metric_Pad1.08x0.95mm_HandSolder
IC7: TPS628101HQWRWYRQ1; TPS6281008QWRWYRQ1; Mouser Part Number TPS628101HQWRWYRQ1
L3: 0.47uH; XFL4012
R114: 100k; R_0603_1608Metric_Pad0.98x0.95mm_HandSolder
R115: 8.06k; R_0603_1608Metric_Pad0.98x0.95mm_HandSolder
R116: 88.7k; R_0603_1608Metric_Pad0.98x0.95mm_HandSolder
R117: 19.6k; R_0603_1608Metric_Pad0.98x0.95mm_HandSolder

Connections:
3V3: C82.1, C83.1, C84.1, C85.1, L3.2, R114.2, R116.2; also elsewhere on the board
5V: C81.1, IC7.1 (MODE/SYNC_1), IC7.2 (VIN), IC7.8 (EN_1), IC7.10 (MODE/SYNC_2), IC7.13 (EN_2); also elsewhere on the board
/MCU/3V3_PG: IC7.9 (PG), R114.1; also elsewhere on the board
/PWR/PWR_3V3/TPS_CF: IC7.7 (COMP/_FSET_1), IC7.12 (COMP/_FSET_2), R115.2
/PWR/PWR_3V3/TPS_FB: C82.2, IC7.5 (FB_1), IC7.11 (FB_2), R116.1, R117.2
GND: C80.2, C81.2, C83.2, C84.2, C85.2, IC7.4 (GND), R115.1, R117.1; also elsewhere on the board
unnamed: C80.1, IC7.6 (SS/TR)
unnamed: IC7.3 (SW), L3.1

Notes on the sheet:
3V3 Supply Place away from 12V supply

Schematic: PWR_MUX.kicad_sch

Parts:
C88: 1u; C_0603_1608Metric_Pad1.08x0.95mm_HandSolder
C96: 1u; C_0603_1608Metric
C97: 100n; C_0603_1608Metric
IC9: TPS2121RUXT; Mouser Part Number 595-TPS2121RUXT
JP11: SolderJumper_2_Bridged; SolderJumper-2_P1.3mm_Bridged_RoundedPad1.0x1.5mm
R119, R121: 18k; R_0603_1608Metric_Pad0.98x0.95mm_HandSolder
R120: 5k; R_0603_1608Metric_Pad0.98x0.95mm_HandSolder
R122: 22.1k; R_0603_1608Metric_Pad0.98x0.95mm_HandSolder

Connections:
3V3: R121.1; also elsewhere on the board
5V: IC9.1 (OUT_1), IC9.8 (OUT_2); also elsewhere on the board
/MCU/PCIE_W_DISABLE: IC9.9 (ST), R121.2; also elsewhere on the board
GND: C88.2, C96.2, C97.2, IC9.4 (OV2), IC9.5 (OV1), IC9.12 (GND), JP11.2 (B), R120.2, R122.2; also elsewhere on the board
LV_5V: IC9.7 (IN1), R119.1; also elsewhere on the board
unnamed: IC9.3 (CP2), JP11.1 (A)
unnamed: IC9.10 (ILIM), R122.1
unnamed: IC9.6 (PR1), R119.2, R120.1
unnamed: C88.1, IC9.11 (SS)
USB_VBUS: C96.1, C97.1, IC9.2 (IN2); also elsewhere on the board

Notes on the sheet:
Ideally place these near the connector

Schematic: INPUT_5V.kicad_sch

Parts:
C12: 100nF; C_0603_1608Metric_Pad1.08x0.95mm_HandSolder
D6: BAT54S; SOT-23
R17: 1k; R_0603_1608Metric_Pad0.98x0.95mm_HandSolder
R18: 1.5k; R_0603_1608Metric_Pad0.98x0.95mm_HandSolder
R19: 100; R_0603_1608Metric_Pad0.98x0.95mm_HandSolder

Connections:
3V3: D6.2 (K); also elsewhere on the board
/CONN_A/AIN_1: R17.1; also elsewhere on the board
/INPUTS/AIN1_IO: C12.1, D6.3, R19.2; also elsewhere on the board
GND: C12.2, D6.1 (A), R18.2; also elsewhere on the board
unnamed: R17.2, R18.1, R19.1

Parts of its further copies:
C48, C50, C51: 100nF; C_0603_1608Metric_Pad1.08x0.95mm_HandSolder
D11, D14, D15: BAT54S; SOT-23
R39, R47, R50: 1k; R_0603_1608Metric_Pad0.98x0.95mm_HandSolder
R40, R48, R51: 1.5k; R_0603_1608Metric_Pad0.98x0.95mm_HandSolder
R42, R49, R52: 100; R_0603_1608Metric_Pad0.98x0.95mm_HandSolder

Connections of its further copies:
3V3: D11.2 (K), D14.2 (K), D15.2 (K); also elsewhere on the board
/CONN_A/AIN_0: R47.1; also elsewhere on the board
/CONN_A/AIN_2: R39.1; also elsewhere on the board
/CONN_A/AIN_3: R50.1; also elsewhere on the board
/INPUTS/AIN0_IO: C50.1, D14.3, R49.2; also elsewhere on the board
/INPUTS/AIN2_IO: C48.1, D11.3, R42.2; also elsewhere on the board
/INPUTS/AIN3_IO: C51.1, D15.3, R52.2; also elsewhere on the board
GND: C48.2, C50.2, C51.2, D11.1 (A), D14.1 (A), D15.1 (A), R40.2, R48.2, R51.2; also elsewhere on the board
unnamed: R39.2, R40.1, R42.1
unnamed: R47.2, R48.1, R49.1
unnamed: R50.2, R51.1, R52.1

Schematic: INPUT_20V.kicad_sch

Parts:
C52: 100nF; C_0603_1608Metric_Pad1.08x0.95mm_HandSolder
D16: BAT54S; SOT-23
R53: 8.2k; R_0603_1608Metric_Pad0.98x0.95mm_HandSolder
R54: 1k; R_0603_1608Metric_Pad0.98x0.95mm_HandSolder
R55: 100; R_0603_1608Metric_Pad0.98x0.95mm_HandSolder

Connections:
3V3: D16.2 (K); also elsewhere on the board
/CONN_A/DIN_1: R53.1; also elsewhere on the board
/INPUTS/DIN1_IO: C52.1, D16.3, R55.2; also elsewhere on the board
GND: C52.2, D16.1 (A), R54.2; also elsewhere on the board
unnamed: R53.2, R54.1, R55.1

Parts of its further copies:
C53, C56, C63, C64: 100nF; C_0603_1608Metric_Pad1.08x0.95mm_HandSolder
D17, D18, D19, D21: BAT54S; SOT-23
R56, R63, R74, R81: 8.2k; R_0603_1608Metric_Pad0.98x0.95mm_HandSolder
R57, R64, R75, R82: 1k; R_0603_1608Metric_Pad0.98x0.95mm_HandSolder
R58, R67, R77, R83: 100; R_0603_1608Metric_Pad0.98x0.95mm_HandSolder

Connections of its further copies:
3V3: D17.2 (K), D18.2 (K), D19.2 (K), D21.2 (K); also elsewhere on the board
12V_PRT: R81.1; also elsewhere on the board
/CONN_A/DIN_0: R63.1; also elsewhere on the board
/CONN_A/DIN_2: R56.1; also elsewhere on the board
/CONN_A/DIN_3: R74.1; also elsewhere on the board
/INPUTS/12V_IO: C64.1, D21.3, R83.2
/INPUTS/DIN0_IO: C56.1, D18.3, R67.2; also elsewhere on the board
/INPUTS/DIN2_IO: C53.1, D17.3, R58.2; also elsewhere on the board
/INPUTS/DIN3_IO: C63.1, D19.3, R77.2; also elsewhere on the board
GND: C53.2, C56.2, C63.2, C64.2, D17.1 (A), D18.1 (A), D19.1 (A), D21.1 (A), R57.2, R64.2, R75.2, R82.2; also elsewhere on the board
unnamed: R56.2, R57.1, R58.1
unnamed: R63.2, R64.1, R67.1
unnamed: R74.2, R75.1, R77.1
unnamed: R81.2, R82.1, R83.1

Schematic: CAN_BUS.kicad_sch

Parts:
C66: 1u; C_0603_1608Metric
C67: 100n; C_0603_1608Metric
IC3: ESD2CAN24DBZRQ1; SOT95P237X112-3N; Mouser Part Number 595-ESD2CAN24DBZRQ1
R85: 120R; R_0603_1608Metric_Pad0.98x0.95mm_HandSolder; not fitted
TP14: CAN_H; TestPoint_THTPad_D2.0mm_Drill1.0mm
TP15: CAN_L; TestPoint_THTPad_D2.0mm_Drill1.0mm
U4: SN65HVD230; SOIC-8_3.9x4.9mm_P1.27mm

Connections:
3V3: C66.1, C67.1, U4.3 (VCC); also elsewhere on the board
/CONN_A/CAN1_H: IC3.2 (IO_2), R85.1, TP14.1, U4.7 (CANH); also elsewhere on the board
/CONN_A/CAN1_L: IC3.1 (IO_1), R85.2, TP15.1, U4.6 (CANL); also elsewhere on the board
/MCU/CAN1_RX: U4.4 (R); also elsewhere on the board
/MCU/CAN1_TX: U4.1 (D); also elsewhere on the board
GND: C66.2, C67.2, IC3.3 (GND), U4.2 (GND), U4.8 (Rs); also elsewhere on the board

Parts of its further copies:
C71: 1u; C_0603_1608Metric
C72: 100n; C_0603_1608Metric
IC5: ESD2CAN24DBZRQ1; SOT95P237X112-3N; Mouser Part Number 595-ESD2CAN24DBZRQ1
R109: 120R; R_0603_1608Metric_Pad0.98x0.95mm_HandSolder; not fitted
TP16: CAN_H; TestPoint_THTPad_D2.0mm_Drill1.0mm
TP17: CAN_L; TestPoint_THTPad_D2.0mm_Drill1.0mm
U5: SN65HVD230; SOIC-8_3.9x4.9mm_P1.27mm

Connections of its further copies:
3V3: C71.1, C72.1, U5.3 (VCC); also elsewhere on the board
/CONN_A/CAN0_H: IC5.2 (IO_2), R109.1, TP16.1, U5.7 (CANH); also elsewhere on the board
/CONN_A/CAN0_L: IC5.1 (IO_1), R109.2, TP17.1, U5.6 (CANL); also elsewhere on the board
/MCU/CAN0_RX: U5.4 (R); also elsewhere on the board
/MCU/CAN0_TX: U5.1 (D); also elsewhere on the board
GND: C71.2, C72.2, IC5.3 (GND), U5.2 (GND), U5.8 (Rs); also elsewhere on the board

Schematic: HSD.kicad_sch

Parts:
C42: 10u; C_0603_1608Metric
C43: 100n; C_0603_1608Metric
D7: 1N4148W; D_SOD-123
IC1: VND7E025AJTR; SOP50P600X170-17N; Mouser Part Number 511-VND7E025AJTR
R24, R25: 100k; R_0603_1608Metric_Pad0.98x0.95mm_HandSolder
R26, R27, R28, R29, R30, R33: 15k; R_0603_1608Metric_Pad0.98x0.95mm_HandSolder
R31: 620R; R_0603_1608Metric_Pad0.98x0.95mm_HandSolder
R32: 4.7k; R_0603_1608Metric_Pad0.98x0.95mm_HandSolder

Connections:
3V3: R33.1; also elsewhere on the board
12V_PRT: C42.1, C43.1, IC1.17 (VCC); also elsewhere on the board
/CONN_A/HSD_2: IC1.13 (OUTPUT0_1), IC1.14 (OUTPUT0_2), IC1.15 (OUTPUT0_3), IC1.16 (OUTPUT0_4); also elsewhere on the board
/CONN_A/HSD_3: IC1.9 (OUTPUT1_1), IC1.10 (OUTPUT1_2), IC1.11 (OUTPUT1_3), IC1.12 (OUTPUT1_4); also elsewhere on the board
/DRIVES/HSD2_CTRL: R24.1, R26.1; also elsewhere on the board
/DRIVES/HSD3_CTRL: R25.1, R30.1; also elsewhere on the board
/DRIVES/HSD23_EN: R27.1; also elsewhere on the board
/DRIVES/HSD23_ISEN: R29.1; also elsewhere on the board
/DRIVES/HSD23_SEL: R28.1; also elsewhere on the board
GND: C42.2, C43.2, D7.1 (K), R24.2, R25.2, R31.1, R32.2; also elsewhere on the board
unnamed: D7.2 (A), IC1.4 (GND), R32.1
unnamed: IC1.7 (CS), R29.2, R31.2
unnamed: IC1.1 (INPUT0), R26.2
unnamed: IC1.8 (INPUT1), R30.2
unnamed: IC1.5 (SEL0), R28.2
unnamed: IC1.3 (SEN), R27.2
unnamed: IC1.2 (~FAULTRST), R33.2

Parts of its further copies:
C68: 10u; C_0603_1608Metric
C69: 100n; C_0603_1608Metric
D23: 1N4148W; D_SOD-123
IC4: VND7E025AJTR; SOP50P600X170-17N; Mouser Part Number 511-VND7E025AJTR
R94, R95: 100k; R_0603_1608Metric_Pad0.98x0.95mm_HandSolder
R96, R97, R98, R99, R100, R103: 15k; R_0603_1608Metric_Pad0.98x0.95mm_HandSolder
R101: 620R; R_0603_1608Metric_Pad0.98x0.95mm_HandSolder
R102: 4.7k; R_0603_1608Metric_Pad0.98x0.95mm_HandSolder

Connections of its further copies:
3V3: R103.1; also elsewhere on the board
12V_PRT: C68.1, C69.1, IC4.17 (VCC); also elsewhere on the board
/CONN_A/HSD_0: IC4.13 (OUTPUT0_1), IC4.14 (OUTPUT0_2), IC4.15 (OUTPUT0_3), IC4.16 (OUTPUT0_4); also elsewhere on the board
/CONN_A/HSD_1: IC4.9 (OUTPUT1_1), IC4.10 (OUTPUT1_2), IC4.11 (OUTPUT1_3), IC4.12 (OUTPUT1_4); also elsewhere on the board
/DRIVES/HSD0_CTRL: R94.1, R96.1; also elsewhere on the board
/DRIVES/HSD1_CTRL: R95.1, R100.1; also elsewhere on the board
/DRIVES/HSD01_EN: R97.1; also elsewhere on the board
/DRIVES/HSD01_ISEN: R99.1; also elsewhere on the board
/DRIVES/HSD01_SEL: R98.1; also elsewhere on the board
GND: C68.2, C69.2, D23.1 (K), R94.2, R95.2, R101.1, R102.2; also elsewhere on the board
unnamed: D23.2 (A), IC4.4 (GND), R102.1
unnamed: IC4.7 (CS), R99.2, R101.2
unnamed: IC4.1 (INPUT0), R96.2
unnamed: IC4.8 (INPUT1), R100.2
unnamed: IC4.5 (SEL0), R98.2
unnamed: IC4.3 (SEN), R97.2
unnamed: IC4.2 (~FAULTRST), R103.2

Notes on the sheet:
RSENSE calculation: K given as 2950, chose 15A Imax: RSENSE = 3.0/(15/2950) = 590 ohms. Closest normal value is 620R. the 3.0 is the target ADC voltage for Imax

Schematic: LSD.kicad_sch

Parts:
R20, R21: 2.2k; R_0603_1608Metric_Pad0.98x0.95mm_HandSolder
R22, R23: 100k; R_0603_1608Metric_Pad0.98x0.95mm_HandSolder
S1: BTS3050EJXUMA1; SOIC127P600X115-9N; Mouser Part Number 726-BTS3050EJXUMA1

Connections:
3V3: R23.1; also elsewhere on the board
/CONN_A/LSD_1: S1.9 (EP); also elsewhere on the board
/DRIVES/LSD1_CTRL: R20.2; also elsewhere on the board
/DRIVES/LSD1_STAT: R21.2; also elsewhere on the board
GND: R22.2, S1.6 (GND_1), S1.7 (GND_2), S1.8 (GND_3); also elsewhere on the board
unnamed: R20.1, R22.1, S1.1 (IN)
unnamed: R21.1, R23.2, S1.3 (STATUS)

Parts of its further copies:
R86, R87, R90, R91, R104, R105: 2.2k; R_0603_1608Metric_Pad0.98x0.95mm_HandSolder
R88, R89, R92, R93, R106, R107: 100k; R_0603_1608Metric_Pad0.98x0.95mm_HandSolder
S2, S3, S4: BTS3050EJXUMA1; SOIC127P600X115-9N; Mouser Part Number 726-BTS3050EJXUMA1

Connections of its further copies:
3V3: R89.1, R93.1, R107.1; also elsewhere on the board
/CONN_A/LSD_0: S2.9 (EP); also elsewhere on the board
/CONN_A/LSD_2: S3.9 (EP); also elsewhere on the board
/CONN_A/LSD_3: S4.9 (EP); also elsewhere on the board
/DRIVES/LSD0_CTRL: R86.2; also elsewhere on the board
/DRIVES/LSD0_STAT: R87.2; also elsewhere on the board
/DRIVES/LSD2_CTRL: R90.2; also elsewhere on the board
/DRIVES/LSD2_STAT: R91.2; also elsewhere on the board
/DRIVES/LSD3_CTRL: R104.2; also elsewhere on the board
/DRIVES/LSD3_STAT: R105.2; also elsewhere on the board
GND: R88.2, R92.2, R106.2, S2.6 (GND_1), S2.7 (GND_2), S2.8 (GND_3), S3.6 (GND_1), S3.7 (GND_2), S3.8 (GND_3), S4.6 (GND_1), S4.7 (GND_2), S4.8 (GND_3); also elsewhere on the board
unnamed: R86.1, R88.1, S2.1 (IN)
unnamed: R87.1, R89.2, S2.3 (STATUS)
unnamed: R90.1, R92.1, S3.1 (IN)
unnamed: R91.1, R93.2, S3.3 (STATUS)
unnamed: R104.1, R106.1, S4.1 (IN)
unnamed: R105.1, R107.2, S4.3 (STATUS)

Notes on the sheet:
Rin calculated by VOHuC(max)/IIN(max). Iinmax is 2mA and VOHuCmax is 3v3. Therefore Rin(min) is 1.6kOhm min. Choosing 2.2k

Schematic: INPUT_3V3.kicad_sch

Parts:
C44: 100nF; C_0603_1608Metric_Pad1.08x0.95mm_HandSolder
D8: BAT54S; SOT-23
R34: 100; R_0603_1608Metric_Pad0.98x0.95mm_HandSolder

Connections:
3V3: D8.2 (K); also elsewhere on the board
/CONN_B/GPIO_1: R34.1; also elsewhere on the board
/GPIO/GPIO1_IO: C44.1, D8.3, R34.2; also elsewhere on the board
GND: C44.2, D8.1 (A); also elsewhere on the board

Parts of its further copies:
C45, C65, C70: 100nF; C_0603_1608Metric_Pad1.08x0.95mm_HandSolder
D9, D22, D24: BAT54S; SOT-23
R35, R84, R108: 100; R_0603_1608Metric_Pad0.98x0.95mm_HandSolder

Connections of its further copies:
3V3: D9.2 (K), D22.2 (K), D24.2 (K); also elsewhere on the board
/CONN_B/GPIO_0: R108.1; also elsewhere on the board
/CONN_B/GPIO_2: R35.1; also elsewhere on the board
/CONN_B/GPIO_3: R84.1; also elsewhere on the board
/GPIO/GPIO0_IO: C70.1, D24.3, R108.2; also elsewhere on the board
/GPIO/GPIO2_IO: C45.1, D9.3, R35.2; also elsewhere on the board
/GPIO/GPIO3_IO: C65.1, D22.3, R84.2; also elsewhere on the board
GND: C45.2, C65.2, C70.2, D9.1 (A), D22.1 (A), D24.1 (A); also elsewhere on the board

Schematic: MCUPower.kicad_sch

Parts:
C13: 4.7uF; C_0603_1608Metric_Pad1.08x0.95mm_HandSolder
C14, C15, C16, C18, C19, C20, C21, C23, C25, C26, C27, C28, C29, C30, C31, C36, C38, C40, C41: 100nF; C_0603_1608Metric_Pad1.08x0.95mm_HandSolder
C17, C33, C39: 1uF; C_0603_1608Metric_Pad1.08x0.95mm_HandSolder
C22, C24, C34: 10uF; C_0603_1608Metric_Pad1.08x0.95mm_HandSolder
C32: 220pF; C_0603_1608Metric_Pad1.08x0.95mm_HandSolder
C35, C37: 2.2uF; C_0603_1608Metric_Pad1.08x0.95mm_HandSolder
FB2: FCM 1608KF-471T03; L_0603_1608Metric_Pad1.05x0.95mm_HandSolder
JP6, JP7: SolderJumper_2_Bridged; SolderJumper-2_P1.3mm_Bridged_RoundedPad1.0x1.5mm
L1: 2.2uH; L_0805_2012Metric_Pad1.05x1.20mm_HandSolder

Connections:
3V3: C13.1, C14.1, C15.1, C16.1, C17.1, C18.1, C19.1, C20.1, C21.1, C22.1, C23.1, C24.1, C25.1, C26.1, C27.1, C28.1, C29.1, C30.1, C31.1, FB2.1; also elsewhere on the board
/MCU/MCU Power/1V2_MCU: C34.1, JP6.1 (A), L1.2
/MCU/MCU Power/VDDLDO: C38.1, C40.1, JP6.2 (B); also elsewhere on the board
/MCU/VCAP: C35.1, C37.1, JP7.1 (A); also elsewhere on the board
/MCU/VFBSMPS: JP7.2 (B); also elsewhere on the board
/MCU/VLXSMPS: C32.1, L1.1; also elsewhere on the board
/MCU/VREF+: C33.1, C36.1, C39.1, C41.1, FB2.2; also elsewhere on the board
GND: C13.2, C14.2, C15.2, C16.2, C17.2, C18.2, C19.2, C20.2, C21.2, C22.2, C23.2, C24.2, C25.2, C26.2, C27.2, C28.2, C29.2, C30.2, C31.2, C32.2, C33.2, C34.2, C35.2, C36.2, C37.2, C38.2, C39.2, C40.2, C41.2; also elsewhere on the board

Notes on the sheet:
AKA VFBSD
AKA VDD_SMPS_OUT Output from switching converter
AKA VDD_SMPS_IN Input supply to switching converter
Analog references
Both caps placed near VDD33USB
This should be a copper pour possibly under the STM on the power layer

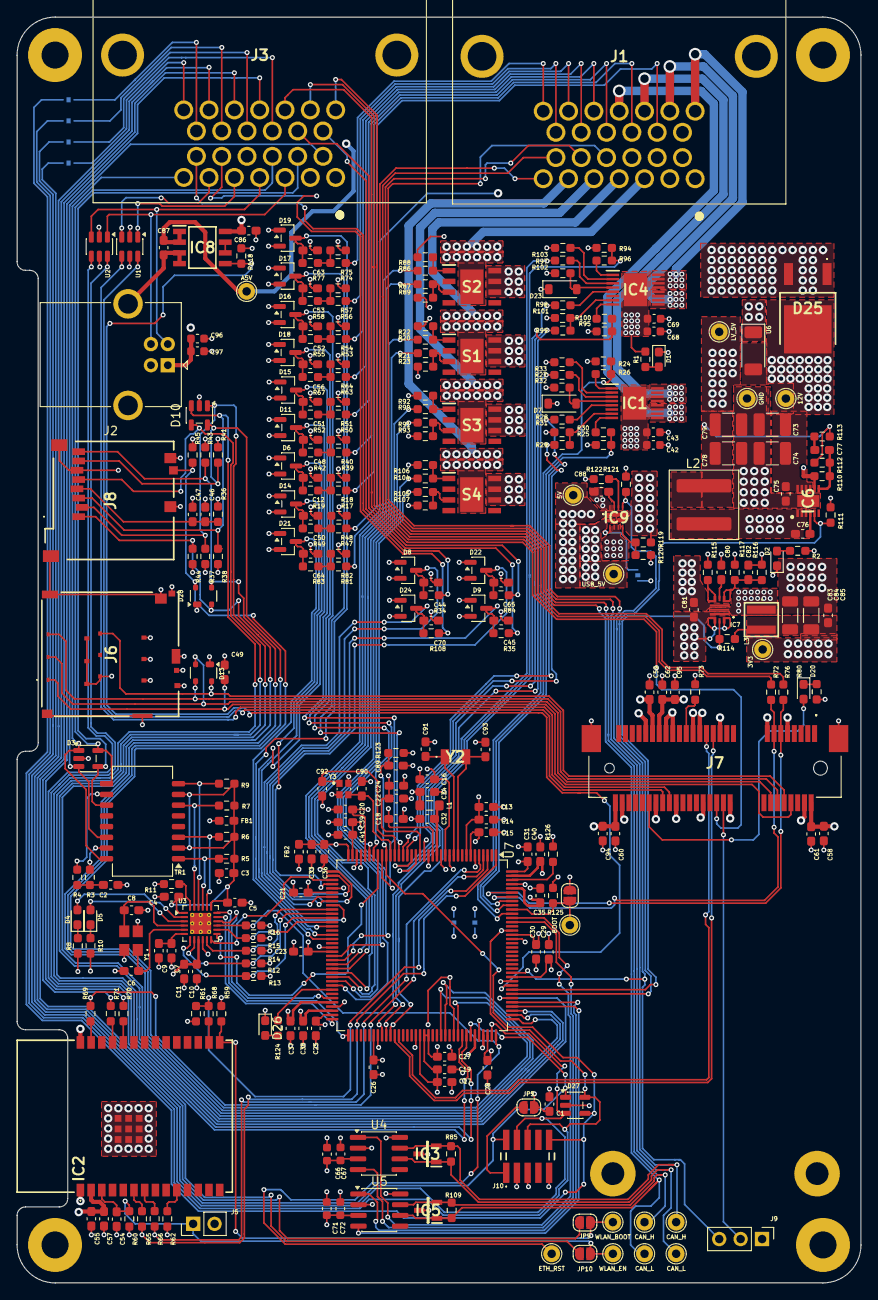
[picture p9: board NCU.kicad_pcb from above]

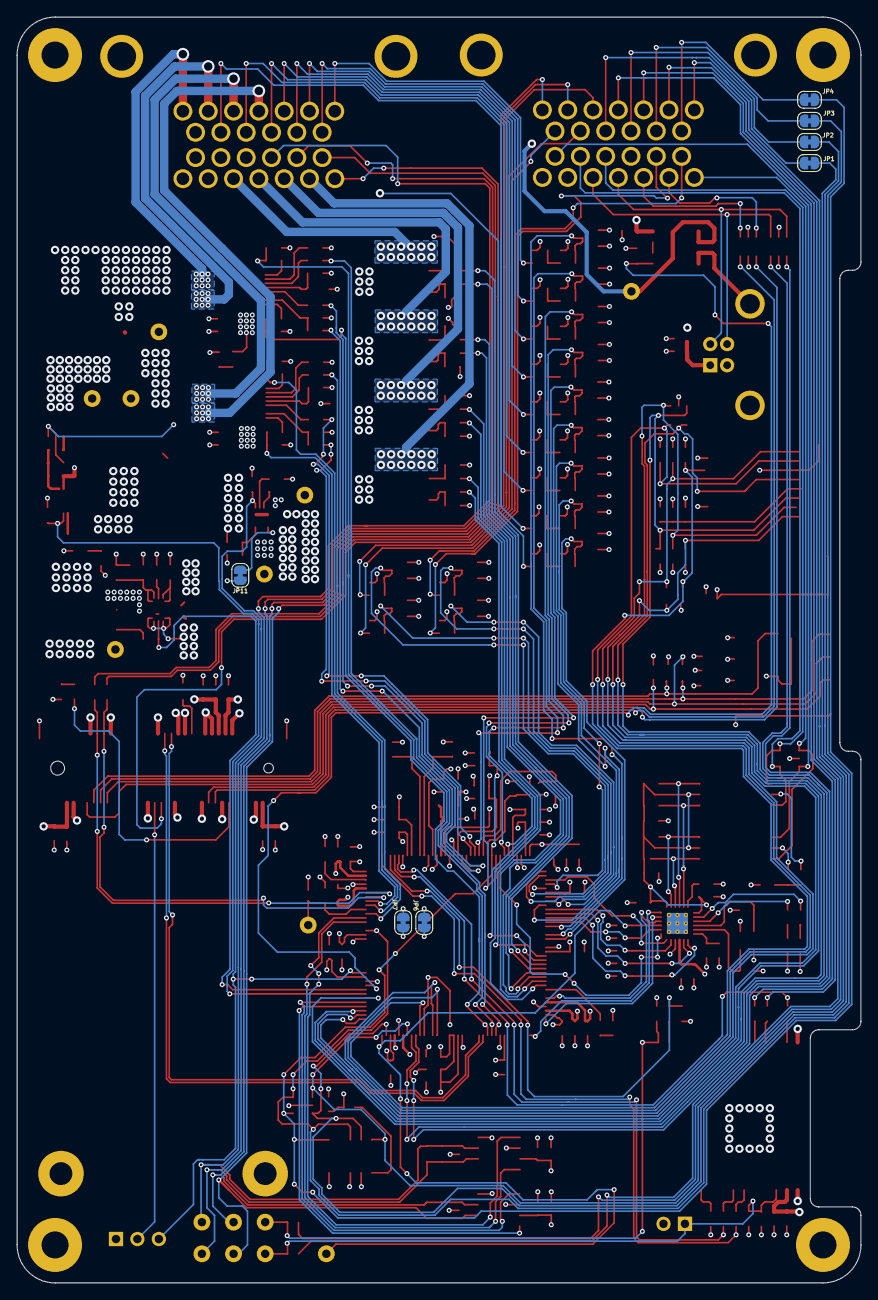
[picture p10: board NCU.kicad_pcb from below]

Board: 4 copper layers, 100.0 x 150.0 mm, 318 parts (7 on the bottom side), 219 nets.

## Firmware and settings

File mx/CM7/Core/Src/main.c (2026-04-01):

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
/* Includes ------------------------------------------------------------------*/
#include "main.h"
#include "gpio.h"

/* USER CODE BEGIN PD */

/* DUAL_CORE_BOOT_SYNC_SEQUENCE: Define for dual core boot synchronization    */
/*                             demonstration code based on hardware semaphore */
/* This define is present in both CM7/CM4 projects                            */
/* To comment when developping/debugging on a single core                     */
#define DUAL_CORE_BOOT_SYNC_SEQUENCE

#if defined(DUAL_CORE_BOOT_SYNC_SEQUENCE)
#ifndef HSEM_ID_0
#define HSEM_ID_0 (0U) /* HW semaphore 0*/
#endif
#endif /* DUAL_CORE_BOOT_SYNC_SEQUENCE */

/* USER CODE END PD */


void SystemClock_Config(void);
static void MPU_Config(void);
/**
  * @brief  The application entry point.
  * @retval int
  */
int main(void)
{

/* USER CODE BEGIN Boot_Mode_Sequence_0 */
#if defined(DUAL_CORE_BOOT_SYNC_SEQUENCE)
  int32_t timeout;
#endif /* DUAL_CORE_BOOT_SYNC_SEQUENCE */
/* USER CODE END Boot_Mode_Sequence_0 */

  /* MPU Configuration--------------------------------------------------------*/
  MPU_Config();

/* USER CODE BEGIN Boot_Mode_Sequence_1 */
#if defined(DUAL_CORE_BOOT_SYNC_SEQUENCE)
  /* Wait until CPU2 boots and enters in stop mode or timeout*/
  timeout = 0xFFFF;
  while((__HAL_RCC_GET_FLAG(RCC_FLAG_D2CKRDY) != RESET) && (timeout-- > 0));
  if ( timeout < 0 )
  {
  Error_Handler();
  }
#endif /* DUAL_CORE_BOOT_SYNC_SEQUENCE */
/* USER CODE END Boot_Mode_Sequence_1 */
  /* MCU Configuration--------------------------------------------------------*/

  /* Reset of all peripherals, Initializes the Flash interface and the Systick. */
  HAL_Init();

  /* Configure the system clock */
  SystemClock_Config();
/* USER CODE BEGIN Boot_Mode_Sequence_2 */
#if defined(DUAL_CORE_BOOT_SYNC_SEQUENCE)
/* When system initialization is finished, Cortex-M7 will release Cortex-M4 by means of
HSEM notification */
/*HW semaphore Clock enable*/
__HAL_RCC_HSEM_CLK_ENABLE();
/*Take HSEM */
HAL_HSEM_FastTake(HSEM_ID_0);
/*Release HSEM in order to notify the CPU2(CM4)*/
HAL_HSEM_Release(HSEM_ID_0,0);
/* wait until CPU2 wakes up from stop mode */
timeout = 0xFFFF;
while((__HAL_RCC_GET_FLAG(RCC_FLAG_D2CKRDY) == RESET) && (timeout-- > 0));
if ( timeout < 0 )
{
Error_Handler();
}
#endif /* DUAL_CORE_BOOT_SYNC_SEQUENCE */
/* USER CODE END Boot_Mode_Sequence_2 */

  /* Initialize all configured peripherals */
  MX_GPIO_Init();
  /* Infinite loop */
  /* USER CODE BEGIN WHILE */
  while (1)
  {
    /* USER CODE END WHILE */

    /* USER CODE BEGIN 3 */
  }
  /* USER CODE END 3 */
}

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
 /* MPU Configuration */

void MPU_Config(void)
{
  MPU_Region_InitTypeDef MPU_InitStruct = {0};

  /* Disables the MPU */
  HAL_MPU_Disable();

  /** Initializes and configures the Region and the memory to be protected
  */
  MPU_InitStruct.Enable = MPU_REGION_ENABLE;
  MPU_InitStruct.Number = MPU_REGION_NUMBER0;
  MPU_InitStruct.BaseAddress = 0x0;
  MPU_InitStruct.Size = MPU_REGION_SIZE_4GB;
  MPU_InitStruct.SubRegionDisable = 0x87;
  MPU_InitStruct.TypeExtField = MPU_TEX_LEVEL0;
  MPU_InitStruct.AccessPermission = MPU_REGION_NO_ACCESS;
  MPU_InitStruct.DisableExec = MPU_INSTRUCTION_ACCESS_DISABLE;
  MPU_InitStruct.IsShareable = MPU_ACCESS_SHAREABLE;
  MPU_InitStruct.IsCacheable = MPU_ACCESS_NOT_CACHEABLE;
  MPU_InitStruct.IsBufferable = MPU_ACCESS_NOT_BUFFERABLE;

  HAL_MPU_ConfigRegion(&MPU_InitStruct);
  /* Enables the MPU */
  HAL_MPU_Enable(MPU_PRIVILEGED_DEFAULT);

}

/**
  * @brief  This function is executed in case of error occurrence.
  * @retval None
  */
void Error_Handler(void)
{
  /* USER CODE BEGIN Error_Handler_Debug */
  /* User can add his own implementation to report the HAL error return state */
  __disable_irq();
  while (1)
  {
  }
  /* USER CODE END Error_Handler_Debug */
}
#ifdef USE_FULL_ASSERT
/**
  * @brief  Reports the name of the source file and the source line number
  *         where the assert_param error has occurred.
  * @param  file: pointer to the source file name
  * @param  line: assert_param error line source number
  * @retval None
  */
void assert_failed(uint8_t *file, uint32_t line)
{
  /* USER CODE BEGIN 6 */
  /* User can add his own implementation to report the file name and line number,
     ex: printf("Wrong parameters value: file %s on line %d\r\n", file, line) */
  /* USER CODE END 6 */
}
#endif /* USE_FULL_ASSERT */

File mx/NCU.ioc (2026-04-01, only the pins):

Mcu.UserName=STM32H745ZITx
PA0.Signal=ADC1_INP16
PA1.Signal=ADC1_INP17
PA11.Signal=USB_OTG_FS_DM
PA12.Signal=USB_OTG_FS_DP
PA2.Signal=ETH_MDIO
PA3.Signal=ADCx_INP15
PA4.Signal=COMP_DAC11_group
PA5.Signal=COMP_DAC12_group
PA6.Signal=ADCx_INP3
PA7.Signal=ETH_CRS_DV
PA9.Signal=USB_OTG_FS_VBUS
PB1.Signal=ADCx_INP5
PB11.Signal=ETH_TX_EN
PB12.Signal=ETH_TXD0
PB13.Signal=ETH_TXD1
PB5.Signal=FDCAN2_RX
PB6.Signal=FDCAN2_TX
PB8.Signal=S_TIM4_CH3
PB9.Signal=S_TIM4_CH4
PC0.Signal=ADCx_INP10
PC1.Signal=ETH_MDC
PC10.Signal=SDMMC1_D2
PC11.Signal=SDMMC1_D3
PC12.Signal=SDMMC1_CK
PC2_C.Signal=ADC3_INP0
PC3_C.Signal=ADC3_INP1
PC4.Signal=ETH_RXD0
PC5.Signal=ETH_RXD1
PC8.Signal=SDMMC1_D0
PC9.Signal=SDMMC1_D1
PD0.Signal=FDCAN1_RX
PD1.Signal=FDCAN1_TX
PD12.Signal=S_TIM4_CH1
PD13.Signal=S_TIM4_CH2
PD14.Signal=UART8_CTS
PD15.Signal=UART8_RTS
PD2.Signal=SDMMC1_CMD
PE0.Signal=UART8_RX
PE1.Signal=UART8_TX
PE11.Signal=S_TIM1_CH2
PE13.Signal=S_TIM1_CH3
PE14.Signal=S_TIM1_CH4
PE2.Signal=SPI4_SCK
PE4.Signal=SPI4_NSS
PE5.Signal=SPI4_MISO
PE6.Signal=SPI4_MOSI
PE9.Signal=S_TIM1_CH1
PF10.Signal=ADC3_INN2
PF11.Signal=ADC1_INP2
PF14.Signal=ADC2_INP6
PF6.Signal=SPI5_NSS
PF7.Signal=SPI5_SCK
PF8.Signal=SPI5_MISO
PF9.Signal=SPI5_MOSI

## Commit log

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2026-02-23 worked on MII pinout
    [MCU.kicad_sch, MCUPower.kicad_sch]
2026-02-23 updated to use RMII and routed ethernet and CAN from micro
    [Ethernet.kicad_sch, MCU.kicad_sch, NCU.kicad_pcb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]
2026-02-25 full initial power scheme
    [CellularModule.kicad_sch, MCU.kicad_sch, NCU.kicad_pcb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]
2026-02-25 improved power supplies, added ADCs
    [AnalogInputs.kicad_sch, NCU.kicad_sch, PowerSupplies.kicad_sch]
2026-03-02 added lib to project and added molex superseal connector
    [AnalogInputs.kicad_sch, NCU.kicad_pcb, NCU.kicad_sch]
2026-03-04 added connects schematic, which is looking quite good
    [CellularModule.kicad_sch, Connectors.kicad_sch, NCU.kicad_pcb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]
2026-03-04 routed more sheets, improved analogs. next 5v /analog ground
    [AnalogInputs.kicad_sch, CARD_SD.kicad_sch, CARD_SIM.kicad_sch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]
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2026-03-05 lsd circuit in place
    [CONN_A.kicad_sch, CONN_B.kicad_sch, DRIVES.kicad_sch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]
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2026-03-05 added 3.3v gpio input protection
    [CARD_SD.kicad_sch, CARD_SIM.kicad_sch, CONN_A.kicad_sch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]
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2026-03-05 possible working power mux
    [CAN_BUS.kicad_sch, HSD.kicad_sch, INPUT_3V3.kicad_sch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]
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2026-03-06 finished initial esp routing
    [CARD_SD.kicad_sch, CARD_SIM.kicad_sch, MCU.kicad_sch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]
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2026-03-06 added dip switches to wireless disables
    [CARD_SIM.kicad_sch, MCU.kicad_sch, MCUPower.kicad_sch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]
2026-03-06 working on mcu layout
    [CONN_B.kicad_sch, MCU.kicad_sch, MCUPower.kicad_sch]
2026-03-06 added oscillators
    [MCU.kicad_sch]
2026-03-06 initial full port selection
    [MCU.kicad_sch, MOD_WLAN.kicad_sch, NCU.kicad_sch]
2026-03-08 redid annotations, added test point
    [CAN_BUS.kicad_sch, CARD_SD.kicad_sch, CARD_SIM.kicad_sch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]
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2026-03-11 added USB protection, reviewed LSD and HSD, improved input TVS footprint
    [CONN_B.kicad_sch, HSD.kicad_sch, LSD.kicad_sch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]
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2026-03-11 updated pcie sd and sim cards
    [CARD_SD.kicad_sch, CARD_SIM.kicad_sch, MOD_PCIE.kicad_sch]
2026-03-11 reannotated, updated some symbols
    [CAN_BUS.kicad_sch, CARD_SD.kicad_sch, CARD_SIM.kicad_sch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]
2026-03-12 minor changes before layout
    [CONN_B.kicad_sch, MCU.kicad_sch, MOD_PCIE.kicad_sch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]
2026-03-12 initial layout of pcb with connectors, wlan and pcie modules
    [MOD_PCIE.kicad_sch, NCU.kicad_pcb, NCU.kicad_sch]
2026-03-12 12v input layout done I think
    [NCU.kicad_pcb, PWR_LV_5V.kicad_sch]
2026-03-12 initial power mux layout
    [NCU.kicad_pcb]
2026-03-12 improved current paths for power supplies
    [NCU.kicad_pcb]
2026-03-12 all power supplies laid out I think
    [NCU.kicad_pcb, PWR.kicad_sch, PWR_A5V.kicad_sch]
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2026-03-13 improved power supplies I think
    [NCU.kicad_pcb]
2026-03-13 improved power input stage, possible drive placement
    [NCU.kicad_pcb]
2026-03-13 better power mux layout
    [NCU.kicad_pcb]
2026-03-13 better placement of analogs incl. analog ldo
    [NCU.kicad_pcb]
2026-03-13 routed hsds and lsds
    [NCU.kicad_pcb]
2026-03-13 routed drives and analogs from conn a
    [NCU.kicad_pcb]
2026-03-13 routing and power for analogs and hsds
    [NCU.kicad_pcb]
2026-03-13 first pass of ethernet phy
    [NCU.kicad_pcb, PHY_ETH.kicad_sch]
2026-03-13 swapped sd to micro sd
    [CARD_SD.kicad_sch, CARD_SIM.kicad_sch, NCU.kicad_pcb]
2026-03-13 updated layout and locked micro location
    [NCU.kicad_pcb]
2026-03-13 laid out most of esp
    [MOD_PCIE.kicad_sch, MOD_WLAN.kicad_sch, NCU.kicad_pcb]
2026-03-13 started routing ethernet and other full length traces
    [NCU.kicad_pcb]
2026-03-13 sd card slot initial attempt
    [NCU.kicad_pcb]
2026-03-13 sd card slot initial attempt (I meant SIM before)
    [CARD_SD.kicad_sch, CONN_B.kicad_sch, MCU.kicad_sch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]
2026-03-14 initial routing of power for pcie, swapped switches for jumpers
    [MOD_PCIE.kicad_sch, MOD_WLAN.kicad_sch, NCU.kicad_pcb]
2026-03-14 rerouted usb and comms signals
    [CONN_B.kicad_sch, NCU.kicad_pcb]
2026-03-14 spread out power and drives more
    [NCU.kicad_pcb]
2026-03-14 full routing of LSD and HSD including control signals
    [NCU.kicad_pcb]
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2026-03-14 routed all traces from superseal connectors down
    [NCU.kicad_pcb]
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2026-03-14 routed can to transceivers
    [NCU.kicad_pcb]
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2026-03-14 routed LSDs to micro
    [MCU.kicad_sch, MCUPower.kicad_sch, NCU.kicad_pcb]
2026-03-14 pcie routing complete (except for status LED)
    [NCU.kicad_pcb]
2026-03-14 started routing down SD lines
    [NCU.kicad_pcb]
2026-03-14 removed solder jumpers for mcu power scheme, as taking up too much space on the board
    [MCUPower.kicad_sch, NCU.kicad_pcb]
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2026-03-14 routed swd, stm ethernet and esp en/boot
    [NCU.kicad_pcb]
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2026-03-14 routed analogs & gpios
    [NCU.kicad_pcb]
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2026-03-18 changed swd connector, removed ground trace between eth and usb lines
    [CONN_B.kicad_sch, NCU.kicad_pcb]
2026-03-18 removed AGND and added ground garden
    [CARD_SD.kicad_sch, CONN_A.kicad_sch, INPUTS.kicad_sch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]
2026-03-18 changed conn a pinout
    [CONN_A.kicad_sch, NCU.kicad_pcb]
2026-03-18 added back in jumpers for internal mcu power
    [MCUPower.kicad_sch, NCU.kicad_pcb]
2026-03-18 added some thermal stiches, no DRC errors
    [NCU.kicad_sch]
2026-03-18 initial drc warnings complete
    [MOD_PCIE.kicad_sch]
2026-03-18 updated design with tweaks to silkscreen and more pours on back copper
    [NCU-B_Cu.gbr, NCU-B_Mask.gbr, NCU-B_Paste.gbr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]
2026-03-19 added 10k resistor to USB VBUS line
    [INPUTS.kicad_sch, MCU.kicad_sch, PWR.kicad_sch]
2026-03-19 added jumper for VCAP connection to 1V2MCU. Fixed resistors on ethernet IF
    [MCUPower.kicad_sch, PHY_ETH.kicad_sch]
2026-03-19 added jumper to external PCIE reset line. removed arrayed component ids and replaced with instance labels
    [MOD_PCIE.kicad_sch]
2026-03-19 updated 3D bodies and gerbers
    [NCU-B_Cu.gbr, NCU-B_Mask.gbr, NCU-B_Paste.gbr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]
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

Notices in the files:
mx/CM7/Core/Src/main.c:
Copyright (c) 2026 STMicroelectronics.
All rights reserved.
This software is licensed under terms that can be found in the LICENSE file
